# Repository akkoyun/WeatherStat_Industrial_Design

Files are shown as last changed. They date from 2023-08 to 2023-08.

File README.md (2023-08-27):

# P101DA<sup>V3</sup> Meteoroloji İstasyonu Tasarım Dokümantasyonu

| Modül Kodu | Açıklama | Durum |
|---|---|---|
| [P101DA-Base](P101DA-Base/Readme.md) | Meteoroloji istasyonu ana ünite | Tasarım bitme aşamasında ana yapı kesinleştirildi |
| [P101DA-Rain](P101DA-Rain/Readme.md) | Kovalı yağmur sensörü ünitesi | Tasarım bitme aşamasında ana yapı kesinleştirildi |
| [P101DA-Soil](P101DA-Soil/Readme.md) | Kademeli toprak sıcaklık sensörü ünitesi  | Tasarım bitme aşamasında ana yapı kesinleştirildi |
| [P101DA-UnderLeaf](P101DA-UnderLeaf/Readme.md) | Yaprak altı sıcaklık ve nem ölçüm ünitesi | V3 versiyonunda kullanılmayacak    |

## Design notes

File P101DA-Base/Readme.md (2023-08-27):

 # P101DA - Meteoroloji İstasyonu Base Ünite  &nbsp; &nbsp; 

| Parça Kodu | Parça Açıklaması | Parça Boyutları | Parça Malzemesi | Kullanım Adedi |
|---|---|---|---|---|
| [C111DA](C111DA/) | Üst Gövde | Ø245 x 100 mm | ABS | 1 |
| [C112BA](C112BA/) | Radyasyon Kalkanı Yaprakları | Ø230 - 46.4 mm  | ABS | 5 |
| [C113CA](C113CA/) | Üst Gövde Alt Kapağı | Ø244.4 - 140 mm | ABS | 1 |
| [C114CA](C114CA/) | Alt Gövde | Ø230 - 54,2 mm  | ABS | 1 |
| [C115BA](C115BA/) | Alt Kapak | Ø235 - 21 mm | ABS | 1 |
| [C116AA](C116AA/) | UV Sensör Merceği | 5x16x36mm | ABS | 1 |
| [PV Cell](PV%20Cell/) | Solar Panel | Ø180 x 2 mm | Monocrystal | 1 |
| [Diğer Parçalar](Diğer/) | | | | |

Bahsi geçen parçalar birleştirilerek P101DA-Base Ünitesi oluşturulmaktadır. </br>

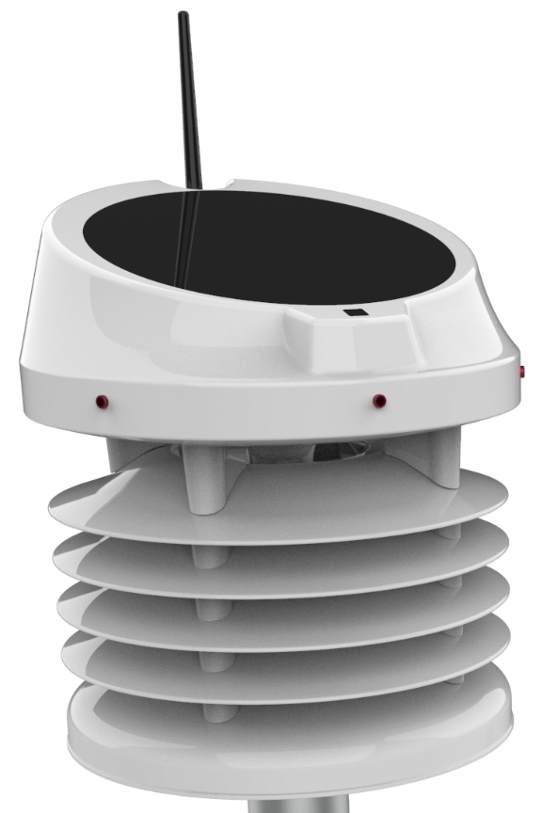
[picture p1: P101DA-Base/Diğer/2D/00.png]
Base ünitenin temsili resmi


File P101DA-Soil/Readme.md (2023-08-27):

# P101DA - Meteoroloji İstasyonu Soil Ünite &nbsp; &nbsp; 

| Parça Kodu | Parça Açıklaması | Parça Boyutları | Parça Malzemesi  | Kullanım Adedi |
|---|---|---|---|---|
| [M403AA](#m403aa) |Sıcaklık Sensörü Alt Metal Parça | |  Pirinç | 1 |
| [M404AA](#m404aa) |Sıcaklık Sensörü Orta Metal Parça  | |  Pirinç | 3 |
| [H903AA](#h903aa) |PVC Boru | |  PVC | 4 |
| [H904AA](#h904aa) |Üst Kapak | |  PVC | 1 |

Bahsi geçen parçalar birleştirilerek P101DA-Soil cihazı plastik aksamı oluşturmaktadır. 

## Eksikler ve Yapılacaklar
- 
</br>

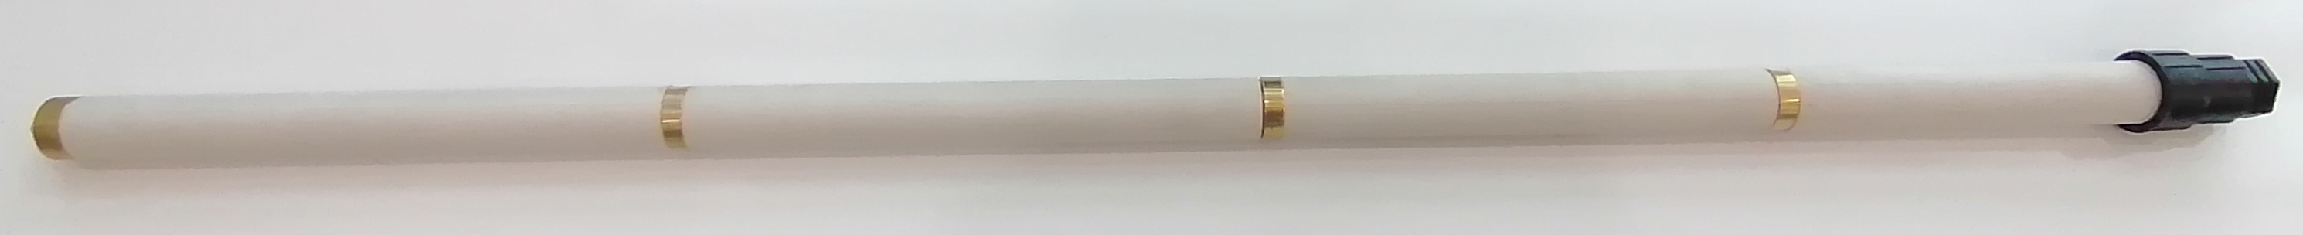
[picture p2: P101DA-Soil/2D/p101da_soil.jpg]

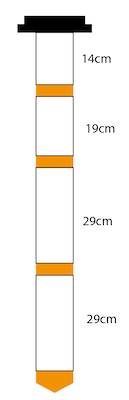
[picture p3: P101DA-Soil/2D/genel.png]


---
# M403AA Sıcaklık Sensörü Alt Metal Parça &nbsp; &nbsp; 
| Parça Kodu | Parça Açıklaması | Parça Boyutları | Parça Malzemesi  | Kullanım Adedi |
|---|---|---|---|---|
| M403AA |Sıcaklık Sensörü Alt Metal Parça | Ø32x38.5 mm |  Pirinç | 1 |

## Açıklama
Toprak altı ısı sensörünün 90cm derinlikteki ısıyı sensöre aktaracak parçadır.</br>
Özel olarak ürettirilmektedir.</br>
İç kısmında NTC sensör yerleştirilen Ø2x8 mm delik vardır.</br>

## Eksikler ve Yapılacaklar
    - 
</br>

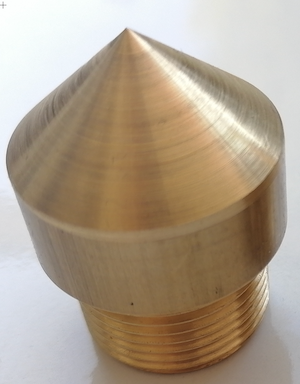
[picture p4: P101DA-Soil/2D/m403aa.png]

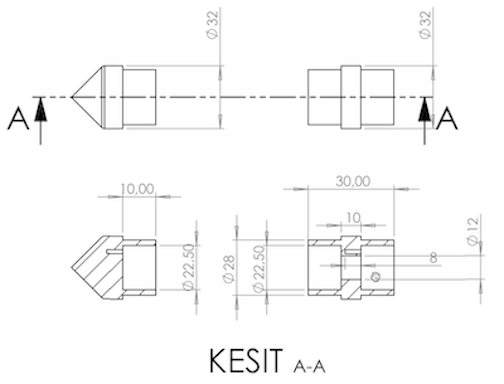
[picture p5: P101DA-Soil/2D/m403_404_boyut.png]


---

# M404AA Sıcaklık Sensörü Orta Metal Parça &nbsp; &nbsp; 
| Parça Kodu | Parça Açıklaması | Parça Boyutları | Parça Malzemesi  | Kullanım Adedi |
|---|---|---|---|---|
| M404AA |Sıcaklık Sensörü Orta Metal Parça | Ø32x30 mm |  Pirinç | 3 |

## Açıklama
Toprak altı ısı sensörünün 10/30/60cm derinlikteki ısıyı sensöre aktaracak parçalardır.</br>
Özel olarak ürettirilmektedir.</br>
İç kısmında NTC sensör yerleştirilen Ø2x8 mm delik vardır.</br>

## Eksikler ve Yapılacaklar
    - 
</br>

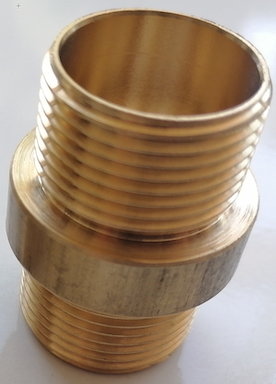
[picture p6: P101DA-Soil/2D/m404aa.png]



---

# H903AA PVC Boru &nbsp; &nbsp; 
| Parça Kodu | Parça Açıklaması | Parça Boyutları | Parça Malzemesi  | Kullanım Adedi |
|---|---|---|---|---|
| H903AA |PVC Boru | Ø32x5mm-29 cm |  PVC | 2 |
| |PVC Boru | Ø32x5mm-19 cm |  PVC | 1 |
| |PVC Boru | Ø32x5mm-14 cm |  PVC | 1 |

## Açıklama
Metal parçaları birleştirmek için kullanılan PVC borulardır.(Dış Çap: 32mm, Et Kalınlığı:5mm)</br>
29/19 cm olan parçalar içten yivlidir(3/4"). Erkek yivli metal parçalar bu yivlere bağlanır.</br>
14 cm olan parçanın bir tarafı dişi yivli (3/4") diğer tarafı erkek yivlidir(1").</br>
Erkek yivli tarafına üst kapak takılır.</br>

## Eksikler ve Yapılacaklar

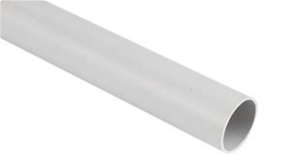
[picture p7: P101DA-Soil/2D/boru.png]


---

# H904AA Üst Kapak &nbsp; &nbsp; 
| Parça Kodu | Parça Açıklaması | Parça Boyutları | Parça Malzemesi  | Kullanım Adedi |
|---|---|---|---|---|
|H904AA |Üst Kapak | |  PVC | 1 |

## Açıklama
1" dişi yivli kör tapadır.</br>
14 cm PVCnin erkek yivli kısmına takılır.</br>
Üzerine G12-4p Mike socket takılacaktır.</br>

## Eksikler ve Yapılacaklar

## __
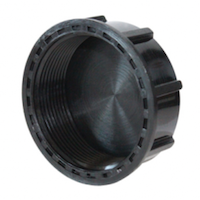
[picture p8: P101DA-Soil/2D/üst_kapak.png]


---

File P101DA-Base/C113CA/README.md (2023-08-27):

# C113CA - Üst Kapak Alt Parçası   &nbsp; &nbsp; 

| Parça Kodu | Parça Açıklaması | Parça Boyutları | Parça Malzemesi | Kullanım Adedi |
| --- | --- | --- | --- | --- |
| C113CA | Üst Kapak Alt Parçası | Ø244.4 - 140 mm | ABS | 1|

## Açıklama
C113CA parçası C111CA ve C112BA parçaları arasında bulunan parçadır.Bu kutunun ölçüleri Ø244 x 139.5 mm olup Ø3mm ölçüsünde olan 4 bağlantı deliğinden C111BA parçasına bağlanmaktadır.

Yan görünümünde bulunan 35,5x19,3mm olan ölçünün merkez deliği Ø1.5 olan delikten tasarlamış olduğumuz Sıcaklık-Nem sensörü bağlantısı yapılır.

Manuel veri gönderme butonu için geliştirdiğimiz PCB kartının üzerinde Ø210 ölçüsünde bulunan ve  Ø3,5 butonun geçeceği delik Ø1.7 olan 2 adet kart bağlantı deliği ile birlikte montajlanacaktır.

15x0.5mm ölçüde olan yarıktan sistemin aktif hale gelmesi için gerekli olan pil bağlantısının altında bulunan bantların dış tarafa çıkarılması için kullanılır.

13,3x6mm olan kanaldan C114BA parçasına bağlı olan mike soketin kablo bağlantısının soketinin geçebilmesi için tasarlanmıştır.

## Teknik Bilgi
Malzeme:ABS Erime Sıcaklığı:210 ~ 280℃ Ağırlık:300 gram Hacim:141 cm3 

## Revizyon \[BA-->CA][08.2022]

    -Pil koruma bandı çizgileri kapatıldı.
    -TH Sensör yeri revize edildi.
    -Üst ünite ile bağlantı şekli değiştirildi.
    -Th sensör kartı için çekmece yapıldı.
</br>

## C113CA <sub> R1<sub> (04.10.2022)
    - Sensör için aşağı inen çıkıntının boyu kısaltıldı.
  
## C113CA <sub> R2<sub> (14.10.2022)
    - Sensör için aşağı inen çıkıntının boyu 26mm uzatıldı.
    - Kart çekmecesi aralığı PCB kalınlığına uygun şekilde 1.6mm yapıldı.

## Maliyet Bilgisi
Bu alana parçanın seri üretim maliyet tabloları yer alacaktır.

    Yapılacak değişiklikler,
    - Yapılan değişikliklere göre mevcut kalıp revizyonu yaptırılacak.

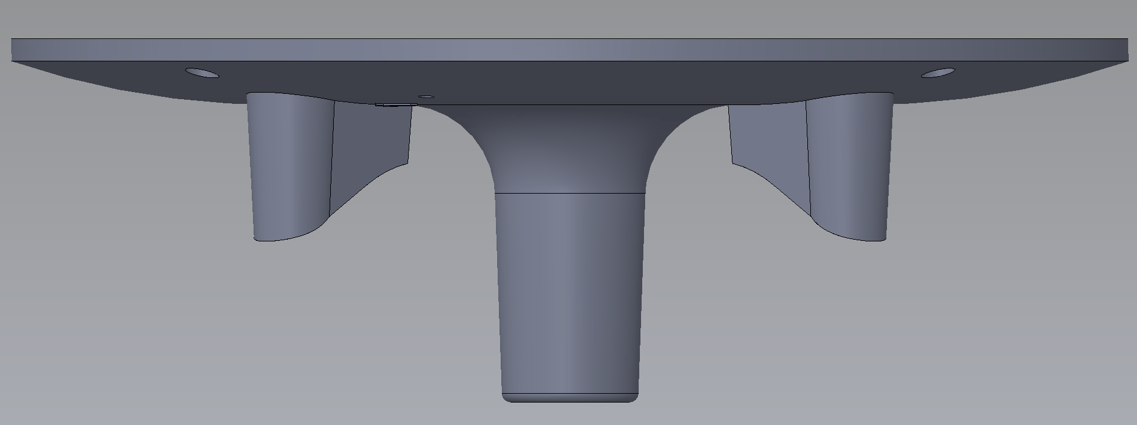
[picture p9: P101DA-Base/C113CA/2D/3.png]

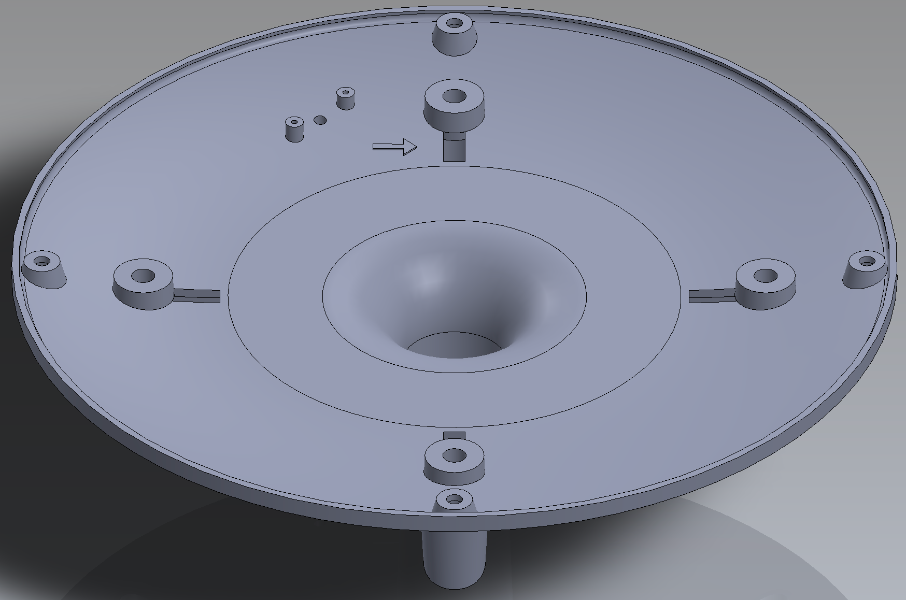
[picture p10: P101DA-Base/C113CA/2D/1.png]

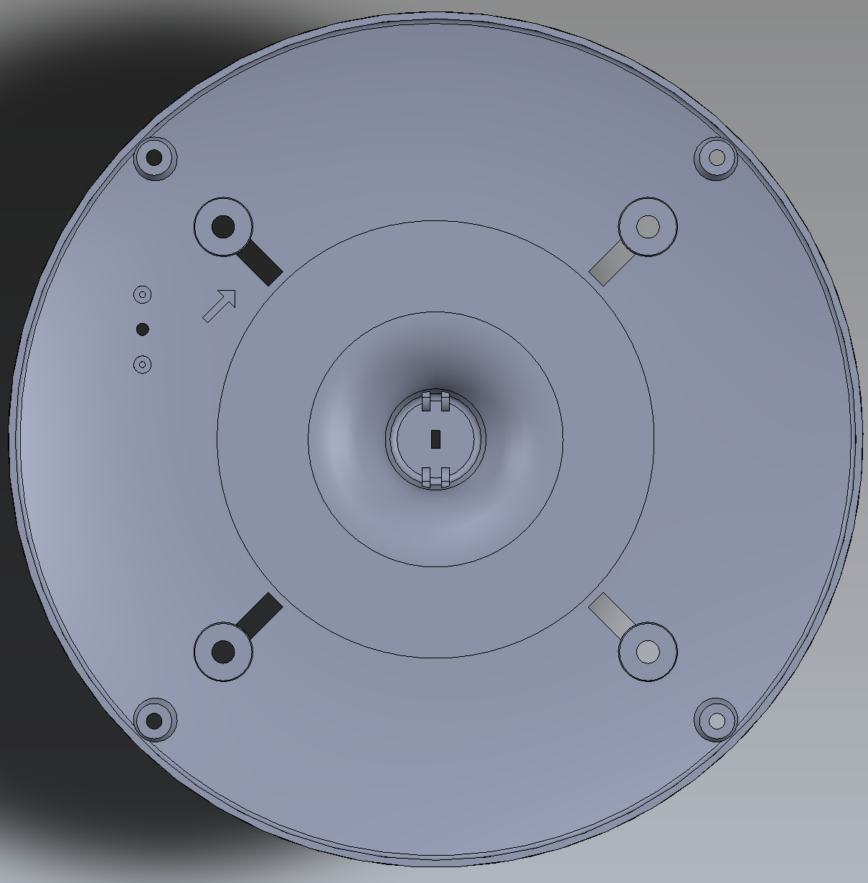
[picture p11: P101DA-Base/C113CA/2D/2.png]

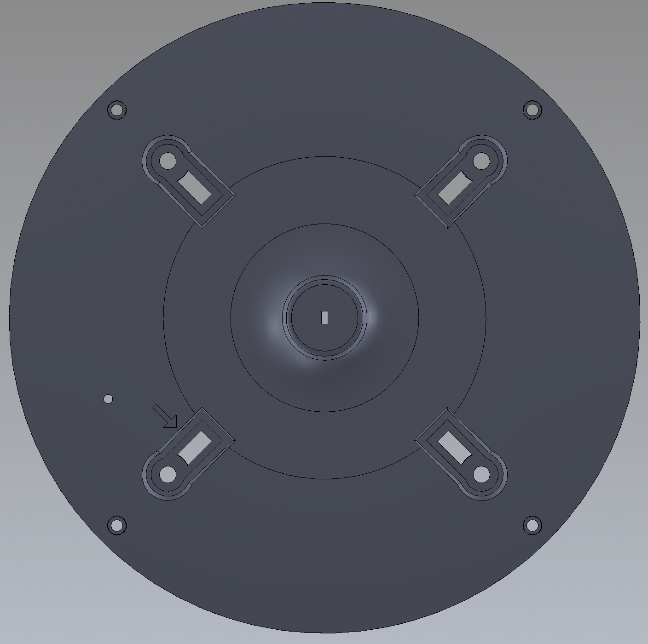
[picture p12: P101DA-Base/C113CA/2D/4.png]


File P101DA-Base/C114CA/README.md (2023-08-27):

# C114CA - Alt Zemin   &nbsp; &nbsp; 

 Parça Kodu | Parça Açıklaması | Parça Boyutları | Parça Malzemesi | Kullanım Adedi |
| ---------- | ---------------- | --------------- | --------------- | -------------- |
| C114CA     | Alt Zemin       | Ø230 x 54.2 mm | ABS             | 1|

## Açıklama
C114CA parçası P101DA ürünün en altında bulunan kapaktır.Bu kapağın ölçüleri Ø230-54,2mm olup Ø171,8mm olan kısımlarından üst parçalarına bağlantı sağlanmaktadır.6,7-16,8mm kanalından alt kısımdan gelen bağlantı soketinin geçeceği kanaldır.

## Teknik Bilgi
Malzeme:ABS Erime Sıcaklığı:210 ~ 280℃ Ağırlık:250 gram Hacim:238 cm3 

## Revizyon \[BA-->CA][08.2022]

    -Kablo geçişler için açık olmayan iki kanal yeri de açıldı.
</br>

## Maliyet Bilgisi
Bu alana parçanın seri üretim maliyet tabloları yer alacaktır.

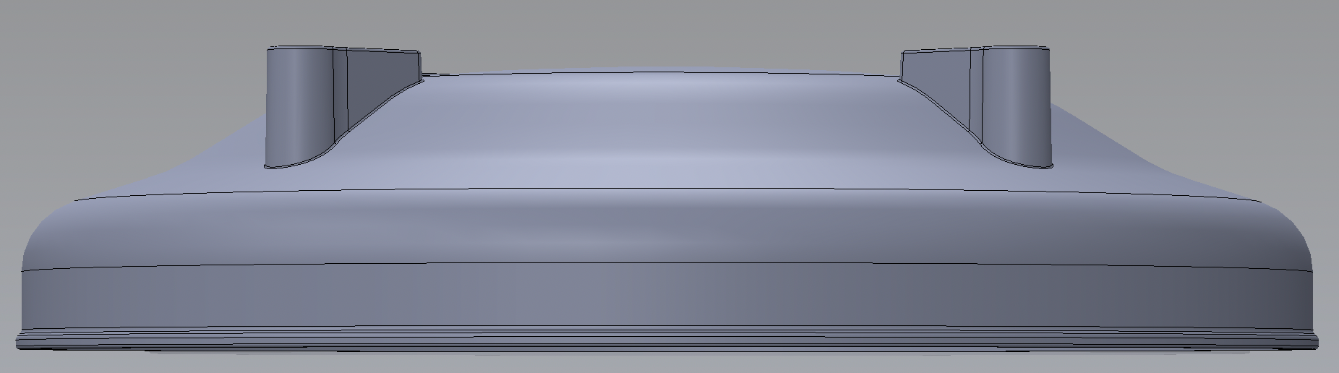
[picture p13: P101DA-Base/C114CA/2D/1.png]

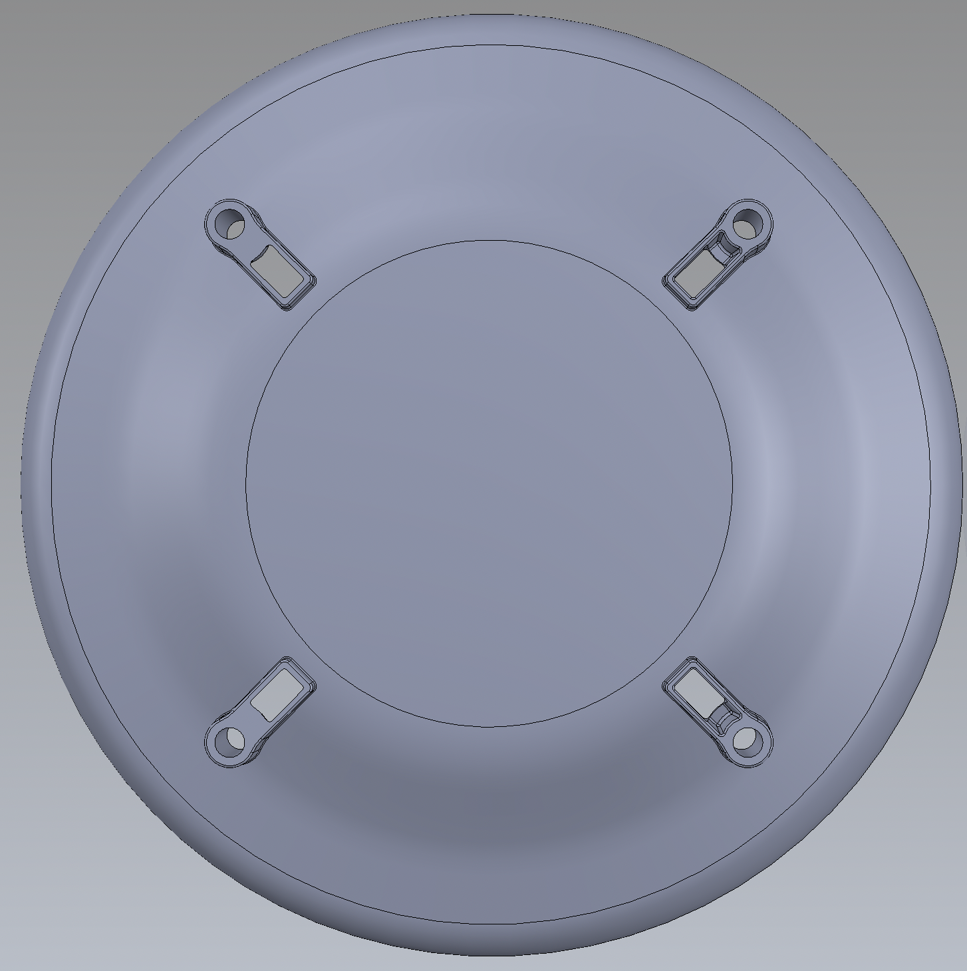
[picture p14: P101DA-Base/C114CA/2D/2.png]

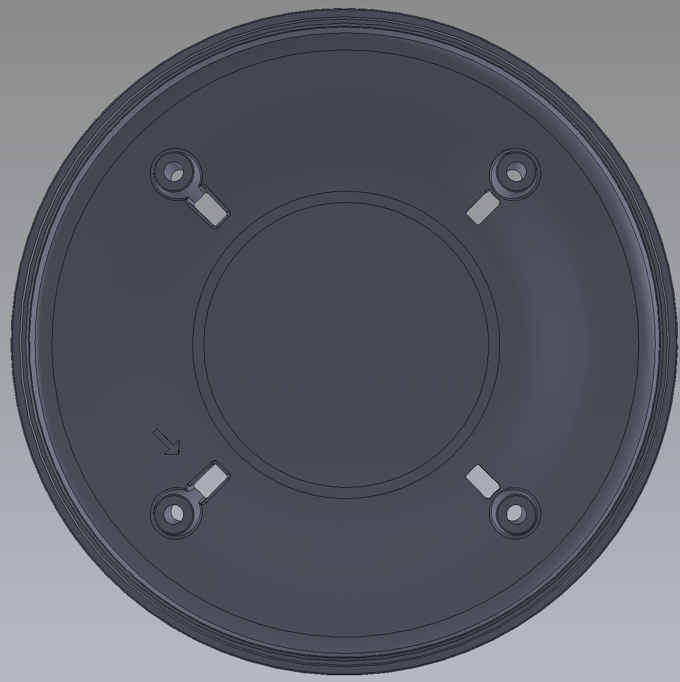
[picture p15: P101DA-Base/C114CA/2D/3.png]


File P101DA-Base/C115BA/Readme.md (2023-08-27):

# C115BA - Alt Kapak   &nbsp; &nbsp; 
| Parça Kodu | Parça Açıklaması | Parça Boyutları | Parça Malzemesi | Kullanım Adedi |
| --- | --- | --- | --- | --- |
| C115BA | Alt kapak | Ø235 x 21 mm | ABS | 1 |
## Açıklama
C115BA parçası P101DA ürününün en altında bulunan kapaktır.Bu kapağın ölçüleri Ø235-21mm olup kapağın merkezinden bağlantı ayağı için 40-30mm'lik dikdörtgen bir delik vardır.

Merkezine doğru mike soketin bağlanması için 12,2-11,1mm'lik bir delik mevcuttur.

Ø171,8mm merkez ölçüsü ve Ø6,5mm'lik 4 adet saplama bağlantı delikleri mevcuttur.

## Teknik Bilgi
Malzeme:ABS Erime Sıcaklığı:210 ~ 280℃ Ağırlık:140 gram Hacim:140,6 cm3 

## Revizyon \[AA-->BA][08.2022]

    - İzi olan soket yeri açıldı.
    - Diğer iki soket yerine ihtiyaç olduğunda kırılabilecek şekilde iz bırakıldı.
</br>

## Maliyet Bilgisi
Bu alana parçanın seri üretim maliyet tabloları yer alacaktır.


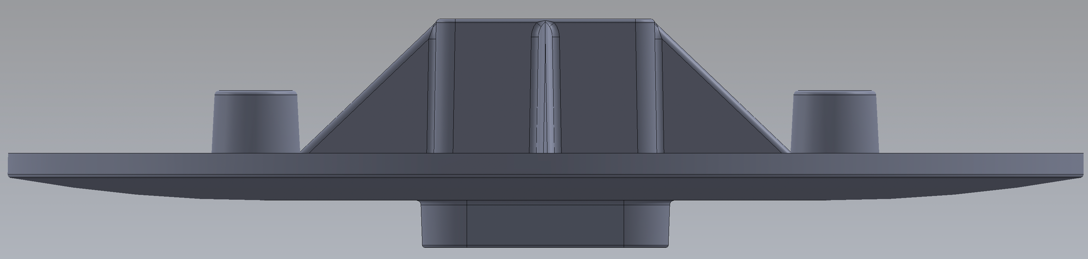
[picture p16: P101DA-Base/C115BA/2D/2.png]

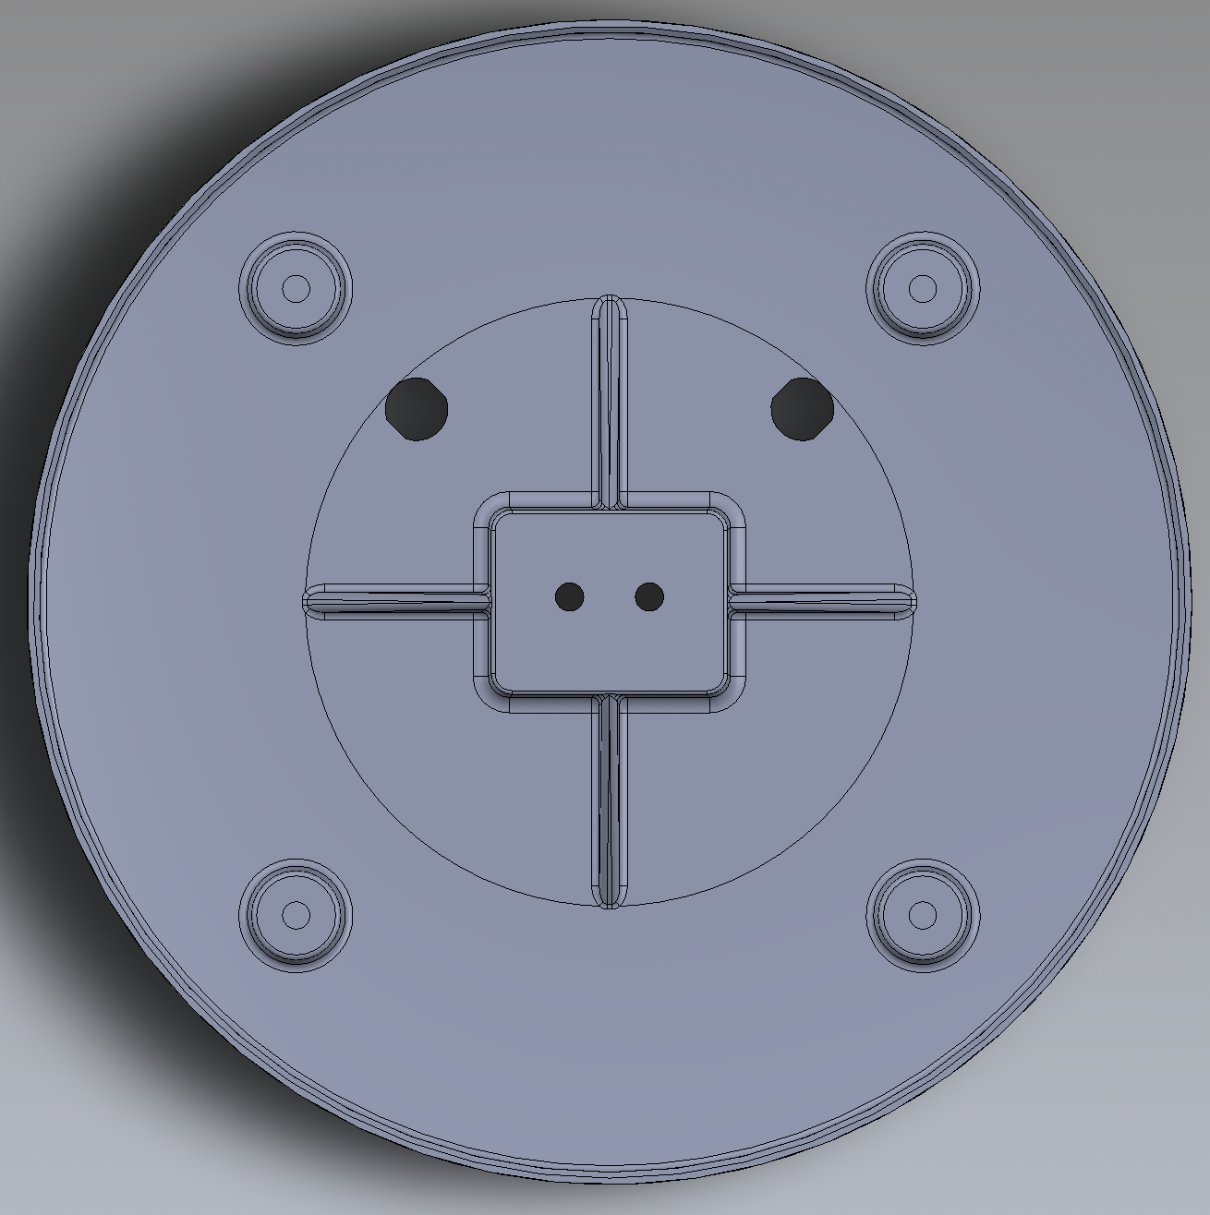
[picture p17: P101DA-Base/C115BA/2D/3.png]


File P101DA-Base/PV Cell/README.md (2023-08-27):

# Solar Panel  &nbsp; &nbsp; 

| Parça Kodu | Parça Açıklaması | Parça Boyutları | Parça Malzemesi | Kullanım Adedi |
| --- | --- | --- | --- | --- |
| SP | Solar Panel | Ø180 x 2 mm | Monocrystal | 1|

## Açıklama
Solar panel monocrystal 5V ?W

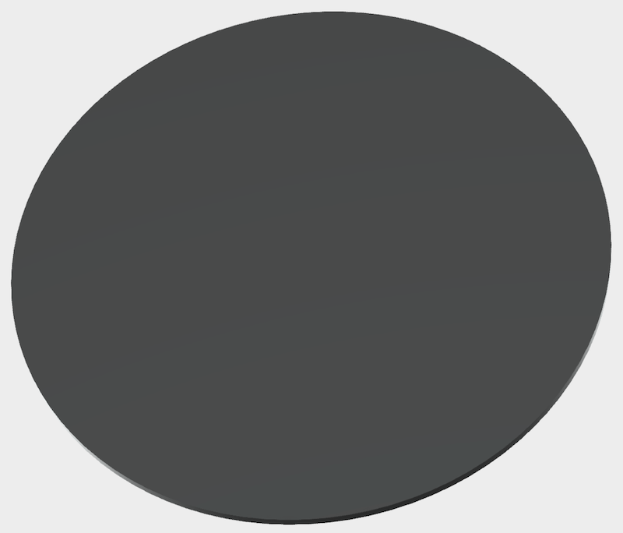
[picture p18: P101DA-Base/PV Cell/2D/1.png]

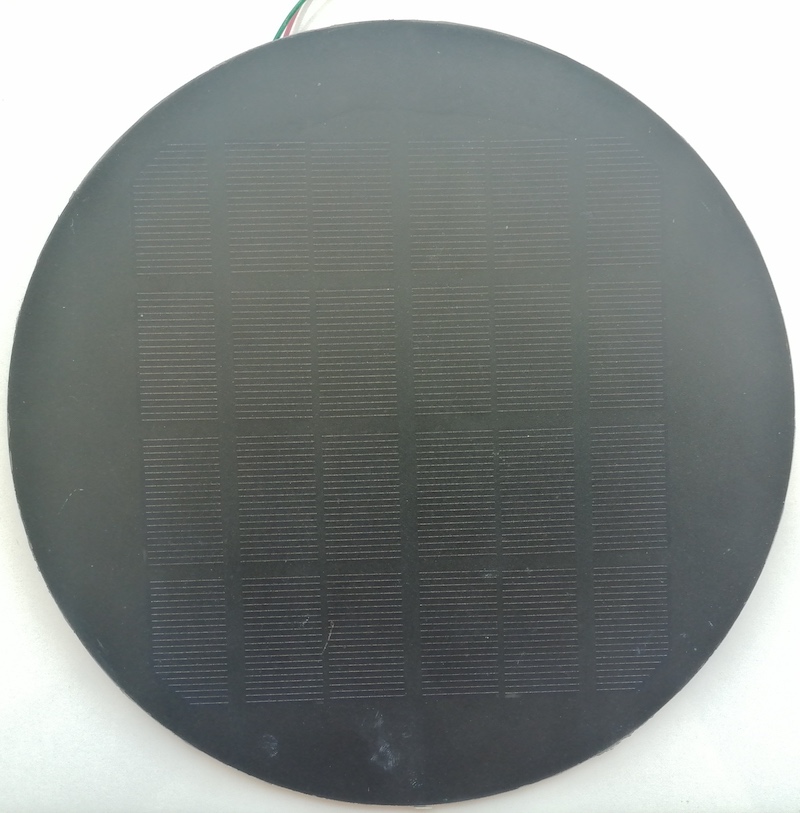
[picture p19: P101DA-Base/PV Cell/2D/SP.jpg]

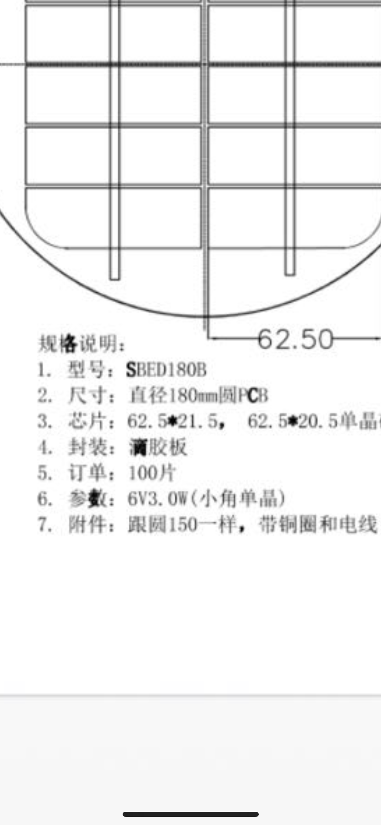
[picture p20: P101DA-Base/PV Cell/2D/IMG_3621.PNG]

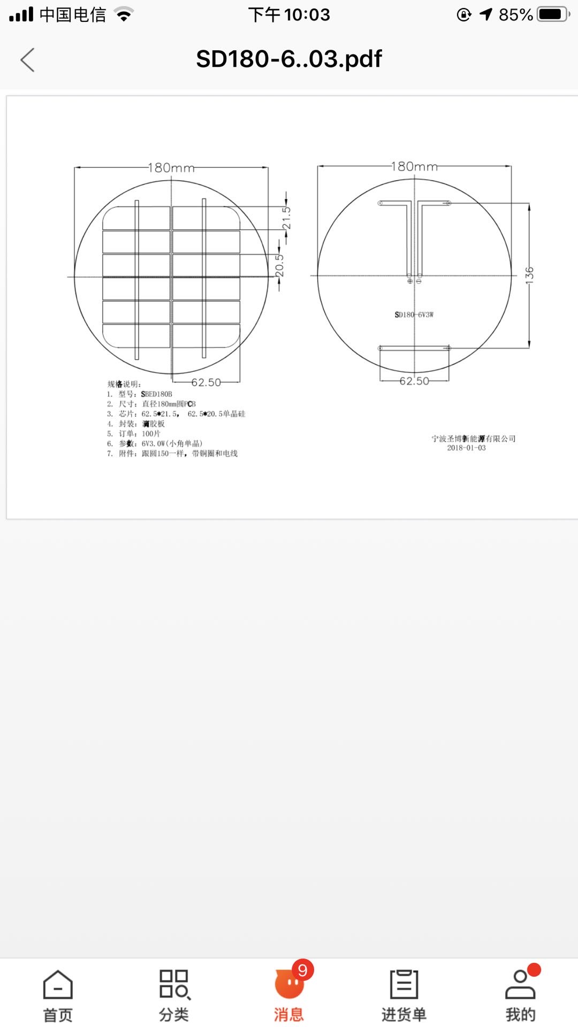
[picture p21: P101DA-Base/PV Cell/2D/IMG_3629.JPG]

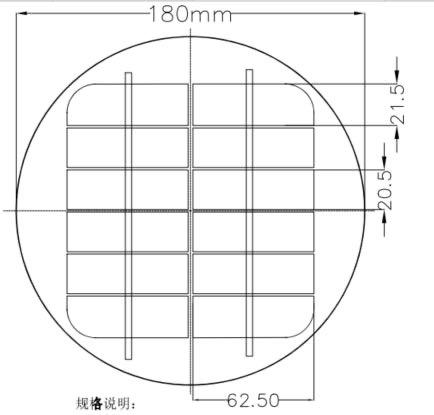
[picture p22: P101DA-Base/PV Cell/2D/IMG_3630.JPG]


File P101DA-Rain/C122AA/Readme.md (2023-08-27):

# C122AA YAĞMUR ÖLÇÜM ALT GÖVDE  &nbsp; &nbsp; 
| Parça Kodu | Parça Açıklaması | Parça Boyutları | Parça Malzemesi | Kullanım Adedi |
| --- | --- | --- | --- | --- |
| C121AA | Alt gövde | Ø213.6 x 42.8 | ABS | 1 |

## Açıklama
Yağmur ölçüm ünitesinin alt kısmıdır. Bu ürün 6 xxx vida ile [C121AA](../C121AA/Readme.md) parçasına bağlanır.</br>
[Kepçe](../C123AA/Readme.md) 5mm [Kepçe Pimi]() ve iki sekman ? ile bu üniteye bağlanır.</br>
[Zemin Düzenleyici Terazi]() bu ünite üzerine yapıştırılır.</br>
Elektronik kart bu ünitedeki kızağa sürülerek takılır ve bulunduğu bölüm epoksi ile doldurulur.</br>
Kepçe hacmi [Kepçe kalibrasyon Vidası](../H111AA/Readme.md) ile ayarlanır.</br>
[Metal Kaide M301AA](../M301AA/Readme.md) 4adet X vida ile bu üniteye bağlanır.</br>

# Maliyet

# Eksikler ve Yapılacaklar
    - Kalibrasyon vidası ve alt kaide bağlantıları için insert/kalıp somun kullanılıyor mu?
    - Kullanılan insert somunların ölçüleri?

# 2D Resimler

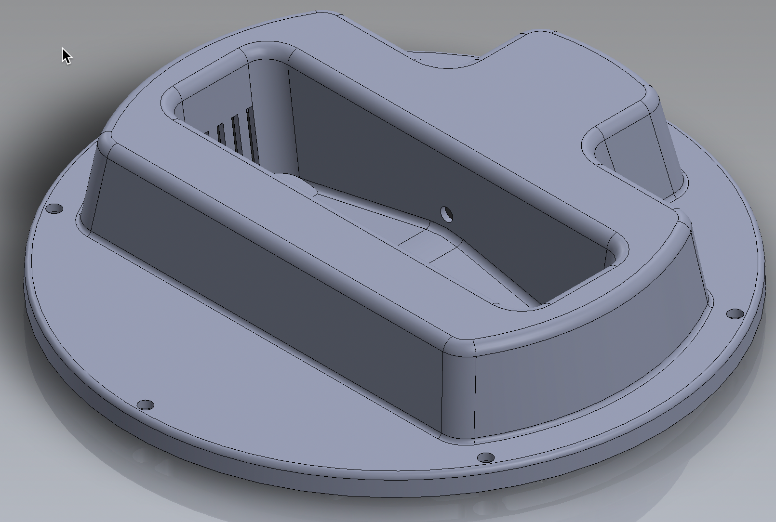
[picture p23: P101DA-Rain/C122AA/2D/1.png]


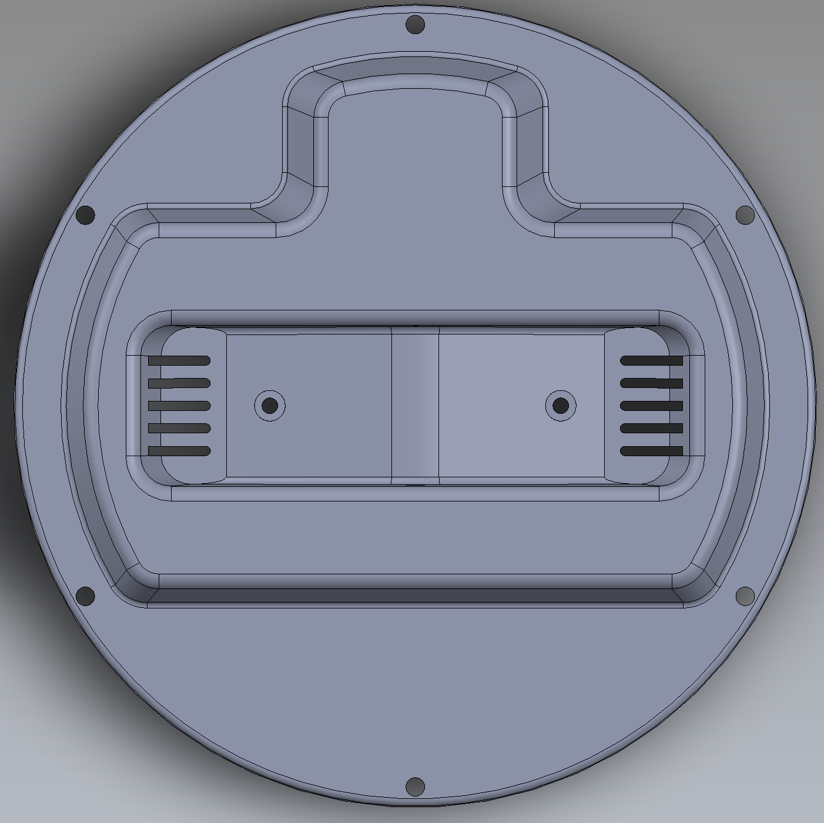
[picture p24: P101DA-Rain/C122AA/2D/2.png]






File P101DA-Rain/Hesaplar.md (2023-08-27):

# Yağmur Modülü Hesaplamaları

**Yağış miktarı:** Yağmur miktarı, toprak yüzeyine düşen suyun, buharlaşmaya ve toprağa 
sızmaya uğramadan, meydana getireceği yükseklik ile tayin olunur. Yağmurun yüksekliği 
milimetre ile ifade edilir, Suyun özgül ağırlığı 1 gr/cm<sup>3</sup> olduğuna 
göre 1 m<sup>2</sup> alanda 1 mm yüksekliğindeki suyun ağırlığı 1 kg eder. 1 m<sup>2</sup> 
yüzey üzerinde 1 mm yüksekliğindeki yağış, 1 cm<sup>2</sup> ye düşen 1 kg yağışa eşittir. 

Yani; 1 mm yağış = 1 kg/m<sup>2</sup> = 1 litredir.

# Su Haznesi Hacmi

| Süre(dk)  | Miktar(mm) | Yer  |  Tarih |
|:--:|---:|:---|---:|
| 5dk| 50.5| HOPA| 7.07.1988|
|10dk| 60.6| HOPA| 7.07.1988|
|15dk| 70.7| HOPA| 7.07.1988|
|30dk| 90.9| HOPA| 7.07.1988|
| 1SA|133.8|BARTIN,ULUS,CEYÜPLER| 10.08.2021|
| 2SA|210.0|BARTIN,ULUS,CEYÜPLER|10-11.08.2021|
| 3SA|252.8|BARTIN,ULUS,CEYÜPLER|10-11.08.2021|
| 4SA|332.3| ANTALYA| 4.11.1995|
| 5SA|374.3| ANTALYA| 4.11.1995|
| 6SA|390.3| ANTALYA| 4.11.1995|
| 8SA|410.4| ANTALYA| 4.11.1995|
|12SA|428.1| ANTALYA| 4.11.1995|
|18SA|464.8| MARMARİS|10-11.12.1992|
|24SA|490.8| ANTALYA-KEMER|16-17.12.2018|

Meteoroloji GM Resmî sitesinde verilen maksimum yağış miktarları incelendiğinde haznemizin 
hacmi 1. Satırdaki 5dk-50,5 mm yağış değerlerini karşılamalıdır. 

Yağış alan yüzey alanımız 16cm çap için $(\pi r^2)$ 0,02 m<sup>2</sup> dir. 
1m<sup>2</sup> 50,5 mm yağış alırsa, 0,02 m<sup>2</sup> 1,01 mm yağış alır.

1 m <sup>2</sup>   &nbsp;&nbsp;&nbsp;&nbsp;&nbsp;&nbsp;50.5 mm

0.02 m <sup>2</sup>   &nbsp;&nbsp;&nbsp;&nbsp;x = 1,01 mm

Bu hesaplamaya göre haznemizin minimum **hacmi** 1,01 lt veya 1010 cm<sup>3</sup> olmalıdır.

# Su Boşalma Süresi

Ölçümlerimizin saatlik periyotlarla yapılacağı düşünüldüğünde belirlenen haznemizin içinde
 bulunan suyun maksimum 1 saat içinde boşalması gerekmektedir. Bunun için kabımızın şekli 
 konik olarak düşünüldüğünde koniğin suyu boşaltma ucunun çapı çok iyi belirlenmelidir. 
 Bunun için 
 [diego.assencio.com](https://diego.assencio.com/?index=62f54ab6114d473b6933ad5bf5a5fc88) 
 sitesindeki hesaplamalardan yararlanılmıştır. Şeklimiz 
 ve oranlar aşağıdaki verilen şekle yakındır.



a = 1,5 = 0,15 cm  mm &nbsp;&nbsp; b = 8cm &nbsp;&nbsp; h1 = 41mm = 4.1cm &nbsp;&nbsp; 
h2 = 27mm = 2.7cm &nbsp;&nbsp; $\pi$ = 3,14

**Silindir Hacmi:** $\pi r^2h$ = 823,936 ∼ 824 cm<sup>3</sup>
 
**Koni Hacmi:** $\pi(R^2+r^2+Rr)/3$ = 184,326 ∼ 184 cm<sup>3</sup>

**Toplam Hacim:** $824+184$ = 1008 cm<sup>3</sup> 

1008 cm<sup>3</sup>  = 1.008 Litre ∼ 1.01 Litre

 

 (g = 98 cm/s<sup>2</sup> )

Bu formül huninin üst çap, alt çap ve yüksekliğinin bilindiği değerler için huninin 
tam boşaltma zamanının hesaplanması için kullanılmaktadır. Kullandığımız şekil 
bu formüle uygulandığı takdirde hesabın gerçek değerlere yakın olacağı düşünülmektedir. 
Formüle yukarda bilinen değerler ve boşaltma çapı için 3mm girildiğinde;

= 211 saniye = **3 dakika 31 saniye**

[**Yapılan Testte Sonuç:** 3  dakika 7 saniye]

(Hesaplanan ile ölçülen arasında 24 saniyelik bir fark var.)

# Kepçe Hacmi

Yukarıda MGM’nün tablosunda verilen 1 saatlik maksimum değer 133 mm olduğuna göre,

kepçe hacmimizi en az 4 ml, en fazla 10 ml olabilir.
Kepçe sayacımızı **1023 puls/saat** olarak alırsak;

Sensörümüz en az 4×1023 = 4,092 litre/saat,
(en fazla 10×1023 = 10,230 litre/saat) ölçüm yapabilir.

Kullanmayı planladığımız 6 ml, $6×1023=6,138$ litre/saat

Çapımız 16cm olarak belirlendiğinde m<sup>2</sup>’ye oran katsayısı $(1/0,02)$'den $50$’dir.

Sensörümüzün saatte en az ölçtüğü 6,138 litre yağmur değeri m<sup>2</sup>'de $6,138×50=306,9$ litredir.

Sonuç olarak **seçtiğimiz değerler maksimum yağış miktarını ölçmeye yeterlidir.**

# Hassasiyet

Hassasiyet = Kepçe Hacmi × 1m<sup>2</sup>'ye oranı

6 ml × 50 =300 ml     (1Lt➔1000mLt➔1mm olduğundan)

**Hassasiyet** = 0,3 mm ‘dir.

# Karşılaştırma Tablosu

|Teknik Özellikleri|[Lambrecht LMP02](https://metos.at/portfolio/lambrecht-rain-gauge/)|[Pessl IM523](https://www.agriexpo.online/prod/pessl-instruments-gmbh/product-169962-14626.html)|[WS-601(Aliexpress)](https://turkish.alibaba.com/product-detail/rainfall-collected-tipping-bucket-rain-gauge-rain-sensor-60654605407.html)|WeatherStat(10 ml)|WeatherStat (10 ml)|birim|
|---|:---:|:---:|:---:|:---:|:---:|:---:|
|Huni Toplama Yüzey çapı | 16  |  16 | 20  | 16  | 16  | cm |
|Kepçe hacmi |  4  |  4  | 16  | 10  | 6  | cm<sup>3|
|Kepçenin dk maksimum devrilmesi |  80 | 60  | 60  | 35  | 68  | boşaltma|
|Darbe sayıcı max değer |4800 |3600 |3600 |2100 |3600 | pulse/h |
|Ölçüm aralığı 0-max |  16 |  12 | 30  |17,5 |20,3 | mm/min  |
|Çözünürlük | 0,2 | 0,2 | 0,5 | 0,5 | 0,3 | mm |
|Doğruluk |  4  |  4  | 10  | 10  |  6  | ±% |
|Huni toplama | 201 | 201 | 314 | 201 | 201 | cm<sup>2|
|Boyutlar / Ağırlık | - | - |  -  | - | - | |

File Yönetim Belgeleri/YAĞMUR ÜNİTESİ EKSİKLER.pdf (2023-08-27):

# YAĞMUR ÜNİTESİ EKSİKLER


C121AA YAĞMUR ÖLÇÜM HUNİ GÖVDE Eksikler Bu parçanın STL ve Step dosyaları eksik. Alt ünite ile bağlantıda kullanılacak 6 vida için kalıba insert somun yerleştirilecek mi?


C122AA YAĞMUR ÖLÇÜM ALT GÖVDE Eksikler ve Yapılacaklar Bu parçanın STL ve Step dosyaları eksik. Kalıba yerleştirilecek kalibrasyon vidası yeri için açık somun(insert) özellikleri Kalıba yerleştirilecek tabla vidalarının somun (insert) özellikleri


C123AA YAĞMUR ÖLÇÜM KEPÇE Bu parçanın STL ve STEP dosyaları eksiktir.

C124AA Taç Kuşkonmaz Pimi 12 adet Eksikler ve Yapılacaklar Hangi malzemeden yapılacağı ve boyutları belirlenecek. Teknik çizimleri eklenecek


C125AA Orta Kuşkonmaz Yuvası STL ve STEP dosyası eksik.

C126AA Orta Kuşkonmaz Pimi 1adet Hangi malzemeden yapılacağı ve boyutları belirlenecek. Teknik çizimleri eklenecek

H111AA Kepçe Kalibrasyon Vidası Alt Ünite C122AA'ya bağlayan 2 vidadır. Boyutları ve teknik resmi eksik.

H112AA Metal Kaide Montaj Vidası (Metal Kaide M301AA'yı Alt Ünite C122AA'ya bağlayan 4 vidadır.) Vida özellikleri ve boyutları eksik


H122AA Seviye Ayar Saplaması (M301AA Metal Kaide’ye kaynatılacak 3 saplama) Özellikleri ve boyutları belirlenecek

H801AA Seviye Ayar Yayı (Kaynatılan saplamalara geçecek) Özellikleri ve boyutları belirlenecek

H301AA Seviye Ayar Somunu Saplamalara montaj kolunun altından sıkılacak 2x3 adet Özellikleri ve boyutları belirlenecek

H401AA Seviye Ayar Yaylı Rondela Somunlarda montaj kolu arasında 1er adet Özellikleri ve boyutları belirlenecek

H701AA Kepçe Pimi Eksik yok


H602AA Kepçe Pimi Segmanı Eksik yok

H901AA Kepçe Mıknatısı Eksik yok

H910AA Baloncuklu Yuvarlak Su Terazisi Eksik yok


M101AA YAĞMUR ÜNİTESİ MONTAJ KOLU Eksikler: sldprt dosyası eksik


M301AA Metal Kaide Eksikler sldprt dosyası yok. Konnektör bağlantı yeri yok.


M302 Montaj Kolu Kelepçesi Sldprt dosyası eksik.


H210 Montaj Kolu U-Cıvata Seti Eksikler Boyutları ve malzeme bilgisi

M113AA Alt Gövde-Huni Bağlantı vidaları 6 adet Eksikler Özellikleri ve boyutları ?

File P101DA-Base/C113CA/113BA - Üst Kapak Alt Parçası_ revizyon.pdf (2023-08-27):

## A Side

## B Side


Buradan itibaren kesilecek
aşağıdakine yakın ovallikte sonlandırılacak

## A Side

## B Side

Sonlandırılan yerde
2x5mm bir açıklık olacak

Bu tarafta da
kartı sokup süreceğimiz
yağmur sensöründeki gibi
kart kızağı olacak
PCB kalınlığı 1,6 mm

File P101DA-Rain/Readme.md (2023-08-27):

# P101DA - Meteoroloji İstasyonu Yağmur Ünitesi &nbsp; &nbsp; 

| Parça Kodu | Parça Açıklaması | Parça Boyutları | Parça Malzemesi  | Kullanım Adedi |
|---|---|---|---|---|
| [C121AA](C121AA/) | Huni Gövdesi | | ABS | 1 |
| [C122AA](C122AA/) | Alt Gövde | | ABS | 1 |
| [C123AA](C123AA/) | Kepçe | | ABS | 1 |
| [C124AA](C124AA/) | Taç Kuşkonmaz Pimi | | ? | 12 |
| [C125AA](C125AA/) | Orta Kuşkonmaz Yuvası | | ABS | 1 |
| [C126AA](C126AA/) | Orta Kuşkonmaz Pimi | | ? | 1 |
| [M101AA](M101AA/) | Montaj Kolu | | Galvanizli Saç ? | 1 |
| [M301AA](M301AA/) | Metal Kaide | | Pas | 1 |
| [M302AA](M302AA/) | Direk Bağlantı Aparatı | | ? | 1 |
| [M401AA](M401AA/) | Kepçe Pimi | | Paslanmaz ? | 1 |
| [Diğer Parçalar](Diğer/) | 

Bahsi geçen parçalar birleştirilerek P101DA-Rain cihazını oluşturmaktadır.

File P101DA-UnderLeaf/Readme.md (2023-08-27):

# P101DA - Meteoroloji İstasyonu UnderLeaf Ünite &nbsp; &nbsp; 

| Parça Kodu | Parça Açıklaması | Parça Boyutları | Parça Malzemesi  | Kullanım Adedi |
|---|---|---|---|---|
| | | | | |

Bahsi geçen parçalar birleştirilerek P101DA-UnderLeaf cihazını oluşturmaktadır. 

***

    Yapılacaklar
    - Tasarım tamamlanacak.

***

    Belgelendirme Yapısı
    * Her bir parçaya ait detay teknik çizim PDF leri (2D klasöründe olacak).
    * Her bir parçaya ait katı modeller (3D klasöründe olacak).
    * Her bir parçaya ait tasarım dosyaları (SolidWorks klasöründe olacak).
    * Her bir parçaya ait malzeme detayları (Parça klasörü readme dosyasında olacak).
    * her bir parçaya ait ağrılık, hacim vb teknik bilgiler (Parça klasörü readme dosyasında olacak).
    * her bir parçaya ait imalat detayları ve maliyet bilgileri (Parça klasörü readme dosyasında olacak).

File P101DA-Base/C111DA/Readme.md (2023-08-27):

# C111DA - Üst Gövde &nbsp; &nbsp; 

| Parça Kodu | Parça Açıklaması | Parça Boyutları | Parça Malzemesi | Kullanım Adedi |
| --- | --- | --- | --- | --- |
| C111DA | Üst Gövde | Ø245 x 100 | ABS | 1 |

## Açıklama
C111DA parçası P101DA ürününün en üst kısmıdır. Bu ürün üzerinde

    -Main PCB (MCU, Pil, Dp Sensörler, diğer çevresel ICs)
    -UV Sensör Kartı
    -UV Sensör Merceği
    -Update Buton Kartı
    -Güneş Paneli
    -GSM ve GPS Anten
    -Rüzgar giriş bağlantı parçaları
parçarları yer almaktadır. 

## Teknik Bilgi
Malzeme:ABS Erime Sıcaklığı:210 ~ 280℃ Ağırlık:? gram Hacim:? cm3

## Maliyet Bilgisi
Bu alana parçanın seri üretim maliyet tabloları yer alacaktır.

## Revizyon \[CA-->DA](26.08.2022)

    -Güneş paneli eğimli hale getirildi.
    -Harici anten yeri iptal edildi. (İç kısımda Stick anten kullanılacak)
    -GPS anteni için iç kısımda 26x26mm yuva yapıldı.
    -Rüzgar ölçüm holleri eklendi. (6 adet)
    -PCB bağlantı yerleri değiştirildi.
    -Alt ünite ile bağlantı yerleri değiştirildi.
</br>

## C111DA  <sub>R1</sub> (04.10.2022)
    - PCB kartı vidalama delik yerleri değiştirildi.

</br>

## C111DA  <sub>R2</sub> (14.10.2022)
    - C111DA_R1 ile C113CA ile montaj uyumsuzluğu tespit edildi. Revize edildi.

</br>

## Yapılacaklar
    - C111DA_R1 ile C113CA birleşme noktası biraz geniş. Sert geçecek şekilde ayarlanacak.

</br>

## __








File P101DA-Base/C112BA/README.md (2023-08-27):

# C112BA - Radyasyon Kalkanı Yaprakları   &nbsp; &nbsp; 

| Parça Kodu | Parça Açıklaması | Parça Boyutları | Parça Malzemesi | Kullanım Adedi |
| --- | --- | --- | --- | --- |
| C112BA | Radyasyon Kalkanı Yaprakları | Ø230 x 46.4 | ABS | 5|

## Açıklama
C112BA parçası P101DA ürünün orta kısmında bulunan ve ürün üzerine 5 adet takılan parçadır.Bu parçanın ölçüleri Ø230-46.4 mm olup Ø172 olan yerinden diğer parçalara bağlanması için iç içe geçmeli bir yapısı vardır.

6.5x13.5 olan alanın birinden toprak sıcaklık sensörünün diğerinden ise Yağmur ölçüm ünitesinin kablosu geçmektedir.

## Teknik Bilgi
Malzeme:ABS Erime Sıcaklığı:210 ~ 280℃ Ağırlık:135 gram Hacim:100 cm3 

## Revizyon

    --
</br>

## Maliyet Bilgisi
Bu alana parçanın seri üretim maliyet tabloları yer alacaktır.










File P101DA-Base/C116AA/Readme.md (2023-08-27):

# C116AA UV Sensör Merceği &nbsp; &nbsp; 

| Parça Kodu | Parça Açıklaması | Parça Boyutları | Parça Malzemesi | Kullanım Adedi |
| --- | --- | --- | --- | --- |
| C116AA | UV Sensör Merceği| 5x16x36mm | ABS | 1 |

## Açıklama
UV Sensör Kartı ile birlikte  [C111DA - Üst Gövde](../C111DA/Readme.md) üzerine montaj edilir.</br>

## Eksikler ve Yapılacaklar
Teknik resim ve sldprt dosyaları eksik.</br>

## __




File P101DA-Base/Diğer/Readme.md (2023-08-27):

# Diğer Parçalar   &nbsp; &nbsp; 

| Parça Kodu | Parça Açıklaması |Parça Boyutları | Parça Malzemesi | Kullanım Adedi |
|---|---|---|---|---|
| [M201AA](#m201aa) | Direk | |  Paslanmaz | 1 |
| [H302AA](#h302aa) | Alt Kapak Kalıp İçi Somun | M6x14 mm |  Pirinç | 4 |
| [H123AA](#h123aa) | Base Toplama Saplaması | Ø6 - 195 mm |  Paslanmaz | 4 |
| [H303AA](#h303aa) | Saplama Sonlandırma Somunu | M6 Flanşlı |  Paslanmaz | 4 |
| [M102AA](#m102aa) | Direk Base Bağlantı Parçası | |  Paslanmaz | 1 |
| [H125AA](#h125aa) | Direk Base Bağlantı Saplaması | Ø6 - 20 mm |  Paslanmaz | 2 |
| [H304AA](#h304aa) | Direk Base Bağlantı Somunu | M6 |  Paslanmaz | 2 |
| [H124AA](#h124aa) | Direk Base Bağlantı Civatası | M5x12 mm |  Paslanmaz | 2 |
| [H305AA](#h305aa) | Direk Base Bağlantı Somunu | M5 |  Paslanmaz | 2 |
| [M402AA](#m402aa) | Rüzgar giriş parçası | |  Pirinç | 6 |
| [H306AA](#h306aa) | Rüzgar giriş kontra somunu | M6 x 3.2mm |  Paslanmaz | 6 |
| [H902AA](#h902aa) | Rüzgar Sensör Hortumu | M6 | Pnomatik Hortumu| 6 |

---
# M201AA Direk &nbsp; &nbsp; 
| Parça Kodu | Parça Açıklaması | Parça Boyutları | Parça Malzemesi | Kullanım Adedi |
|---|---|---|---|---|
| M201AA | Direk |  2 metre? | 50x50x2mm Profil| 1 |

## Açıklama
[Meteoroloji Base Unitesi](../../P101DA-Rain/Readme.md) bu direğin üstüne [Direk Base Bağlantı Parçası](#m102aa-direk-base-bağlantı-parçası) ile bağlanır.</br>
Direğin alt ucu yere saplama şeklinde geçmesi planlanmaktadır.</br>

## Eksikler ve Yapılacaklar
Direğin üst kısmında [Direk Base Bağlantı Parçası](#m102aa-direk-base-bağlantı-parçası)nın bağlanacağı yerdeki deliklerin yeri ve çapı</br>



---

# H302AA Alt Kapak Kalıp İçi Somun &nbsp; &nbsp; 

| Parça Kodu | Parça Açıklaması | Parça Boyutları | Parça Malzemesi | Kullanım Adedi |
|---|---|---|---|---|
| H302AA | Alt Kapak Kalıp İçi Somun | Ø6x14 mm |  Pirinç | 4 |

## Açıklama

[H123AA Saplama](#h302aa-alt-kapak-kalıp-i̇çi-somun)nın bağlandığı somunlardır. </br>


---

# H123AA Base Toplama Saplaması &nbsp; &nbsp; 

| Parça Kodu | Parça Açıklaması | Parça Boyutları | Parça Malzemesi | Kullanım Adedi |
|---|---|---|---|---|
| H123AA | Base Toplama Saplaması | Ø6 - 195 mm |  Paslanmaz | 4 |

## Açıklama
Base ünitesinin [C115AA - Alt Kapak](../C115AA/README.md)'a  bağlanan ve üst kısım hariç diğer parçaları toplayan saplamadır.</br>



---

# H303AA Saplama Sonlandırma Somunu &nbsp; &nbsp; 

| Parça Kodu | Parça Açıklaması | Parça Boyutları | Parça Malzemesi | Kullanım Adedi |
|---|---|---|---|---|
| H303AA | Saplama Sonlandırma Somunu | Ø6 mm Flanşlı |  Paslanmaz | 4 |

## Açıklama
[H123AA Saplaması](../H123AA/Readme.md)nı sonlandıran somunlardır. </br>



---

# M102AA Direk Base Bağlantı Parçası &nbsp; &nbsp; 
| Parça Kodu | Parça Açıklaması | Parça Boyutları | Parça Malzemesi | Kullanım Adedi |
|---|---|---|---|---|
| M102AA | Direk Base Bağlantı Parçası  | |  Paslanmaz | 1 |

## Açıklama
[Direk](#m201aa-direk) ile [P101DA-Base](../../P101DA-Base/Readme.md) üniteyi birleştiren parçadır.</br>
Üzerine 2 adet [Saplama](#h125aa-direk-base-bağlantı-saplaması) kaynatılır.</br>
Bu 2 saplama Direk üzerindeki deliklere geçer ve 2 adet [somun](#h304aa-m6-somun) bağlanır. </br>
Bu parça Ana Üniteye [H124AA Civatası](#h124aa-direk-base-bağlantı-civatası) ve 2 adet [M5 Somun](#h305aa-direk-base-bağlantı-somunu) ile bağlanır. </br>

## Eksikler ve Yapılacaklar
Parçanın çizimi eksik.</br>







---
</br>

# H125AA Direk Base Bağlantı Saplaması  &nbsp; &nbsp; 

| Parça Kodu | Parça Açıklaması | Parça Boyutları | Parça Malzemesi | Kullanım Adedi |
|---|---|---|---|---|
| H125AA | Direk Base Bağlantı Saplaması| Ø6 - 20 mm |  Paslanmaz | 2 |

## Açıklama
Bağlantı parçasının üzerine kaynatılan 2 adet saplamadır.</br>



---

# H304AA M6 Somun   &nbsp; &nbsp; 

| Parça Kodu | Parça Açıklaması | Parça Boyutları | Parça Malzemesi | Kullanım Adedi |
|---|---|---|---|---|
| H304AA | Direk Base Bağlantı Somunu | M6 |  Paslanmaz | 2 |

## Açıklama
Bağlantı parçasının direğe bağlayan somunlardır.</br>



---

# H124AA Direk Base Bağlantı Civatası   &nbsp; &nbsp; 

| Parça Kodu | Parça Açıklaması | Parça Boyutları | Parça Malzemesi | Kullanım Adedi |
|---|---|---|---|---|
| H124AA | Direk Base Bağlantı Civatası | M5x12 mm |  Paslanmaz | 2 |

Bağlantı parçasının Ana üniteye bağlayan civatalardır.</br>


---

# H305AA Direk Base Bağlantı Somunu   &nbsp; &nbsp; 

| Parça Kodu | Parça Açıklaması | Parça Boyutları | Parça Malzemesi | Kullanım Adedi |
|---|---|---|---|---|
| H305AA | Direk Base Bağlantı Somunu | M5 |  Paslanmaz | 2 |

Bağlantı parçasının Ana üniteye bağlayan civataları bağlar.</br>


---
# M402AA Rüzgar Giriş Parçası &nbsp; &nbsp; 
| Parça Kodu | Parça Açıklaması | Parça Boyutları | Parça Malzemesi | Kullanım Adedi |
|---|---|---|---|---|
|  M402AA | Rüzgar giriş parçası | 14x10 mm |  Pirinç | 6 |
## Açıklama
Base ünitesi üzerinde bulunan rüzgar giriş hollerine takılır.</br>
Özel olarak ürettirilmektedir. </br>
m6 x 3.2 mm kontra somun ile bağlanmaktadır. </br>
İç tarafından hortum ile DP sensörlerine bağlanmaktadır. </br>




---

# H306AA Rüzgar giriş kontra somunu &nbsp; &nbsp; 
| Parça Kodu | Parça Açıklaması | Parça Boyutları | Parça Malzemesi | Kullanım Adedi |
|---|---|---|---|---|
|  H306AA | Rüzgar giriş kontra somunu | M6 x 3.2mm |  Paslanmaz | 6 |
## Açıklama
Rüzgar giriş parçasını base üniteye sabitleyen somundur. </br>


---
# H902AA Rüzgar Sensör Hortumu  &nbsp; &nbsp; 
| Parça Kodu | Parça Açıklaması | Parça Boyutları | Parça Malzemesi | Kullanım Adedi |
|---|---|---|---|---|
|  H902AA | Rüzgar Sensör Hortumu | M6 |Pnomatik Hortumu | 6 |
## Açıklama
Rüzgar giriş parçalarından alınan basıncı DP sensörlere ileten hortumdur.</br>


---

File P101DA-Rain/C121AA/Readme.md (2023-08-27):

# C121AA YAĞMUR ÖLÇÜM HUNİ GÖVDE &nbsp; &nbsp; 

| Parça Kodu | Parça Açıklaması | Parça Boyutları | Parça Malzemesi | Kullanım Adedi |
| --- | --- | --- | --- | --- |
| C121AA | Huni gövdesi | Ø218 x 138.4 mm | ABS | 1 |

## Açıklama
Yağmur ölçüm ünitesinin huni gövdesi kısmıdır. Bu ürün 6 xxx vida ile [C122AA](../C122AA/Readme.md) parçasına bağlanır.</br>
Huninin boşaltım deliğinin üst kısmına sert geçme yöntemiyle [C125AA](../C125AA/Readme.md) Orta Kuşkonmaz parçası bağlanır.</br>
Üst kısmında 12 adet 3,2 ?mm kalınlığında [C126AA](../C123AA/Readme.md) Taç kuşkonmaz pimi takılacaktır.</br>

# Maliyet

## __









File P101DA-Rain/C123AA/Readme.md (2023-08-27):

# C123AA YAĞMUR ÖLÇÜM KEPÇE  &nbsp; &nbsp; 
| Parça Kodu | Parça Açıklaması | Parça Boyutları | Parça Malzemesi | Kullanım Adedi |
| --- | --- | --- | --- | --- |
| C123AA | Kepçe | 124x47.5x42 mm  | ABS | 1 |

## Açıklama
Kepçe [Kepçe Bağlantı Pimi H601AA](../H601AA/Readme.md) ile [Alt Gövde](../C122AA/Readme.md)ye bağlanır.</br>
Üzerine 2 adet [Kepçe Mıknatısı H901AA](../H901AA/Readme.md) yapıştırılır.</br>

# Maliyet

# Eksikler ve Yapılacaklar
## __







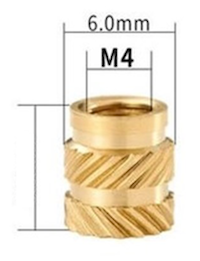
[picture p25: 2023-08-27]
P101DA-Rain/Diğer/2D/insert.png

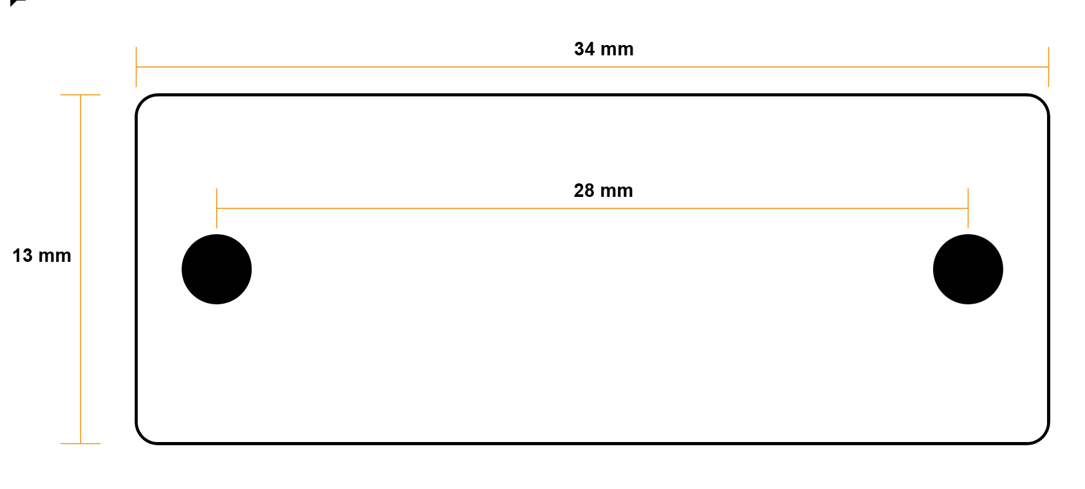
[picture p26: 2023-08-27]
P101DA-Base/C111DA/Documents/UV_PCB_Dimension.png

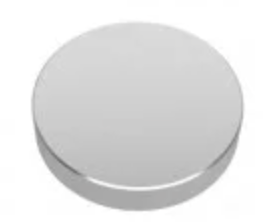
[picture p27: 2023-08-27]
P101DA-Rain/Diğer/2D/mıknatıs.png

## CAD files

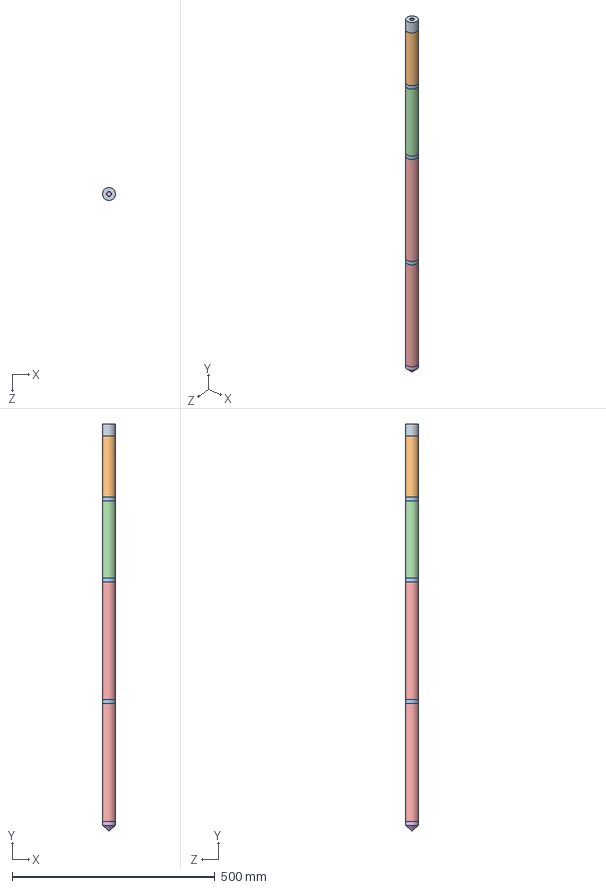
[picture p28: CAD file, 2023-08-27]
P101DA-Soil/Solidworks/Soil_Montaj.SLDASM
32.0 x 1004.0 x 32.0 mm
yivli son
15 cm
yivli ara x 3
19 cm
29 cm x 2
yivli baş

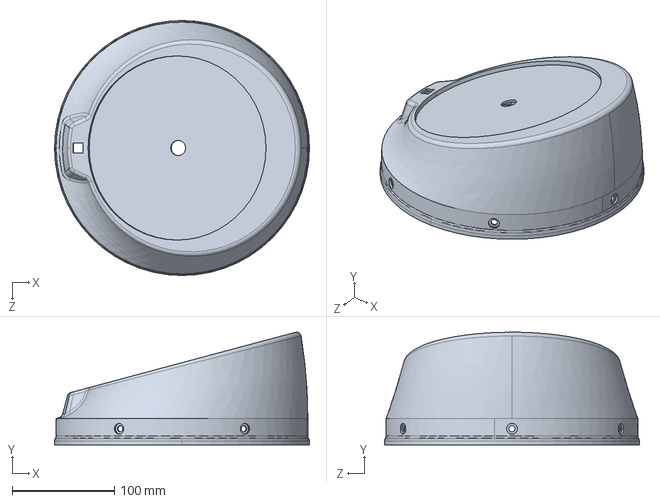
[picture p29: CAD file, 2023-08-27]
P101DA-Base/C111DA/3D/C111DA_R2.STEP
249.3 x 110.2 x 249.3 mm

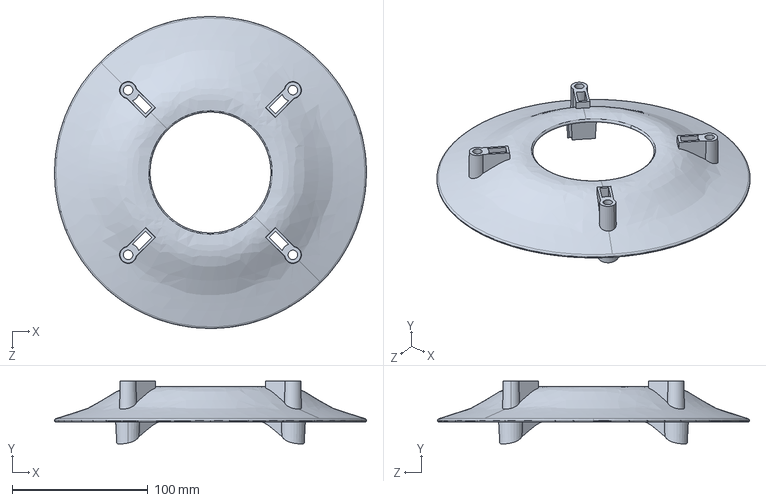
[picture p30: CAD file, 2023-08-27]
P101DA-Base/C112BA/3D/C112BA.STEP
230.0 x 46.4 x 230.0 mm

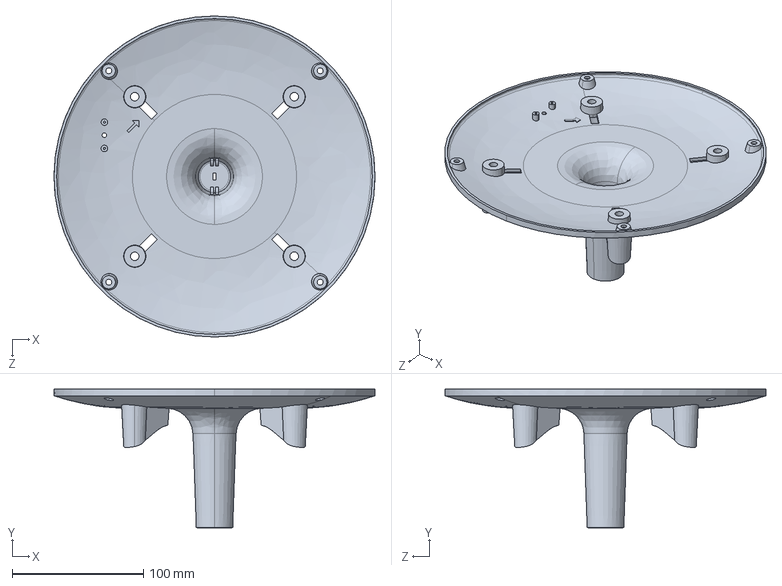
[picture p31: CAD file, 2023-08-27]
P101DA-Base/C113CA/3D/C113CA_R2.STEP
244.4 x 105.5 x 244.4 mm

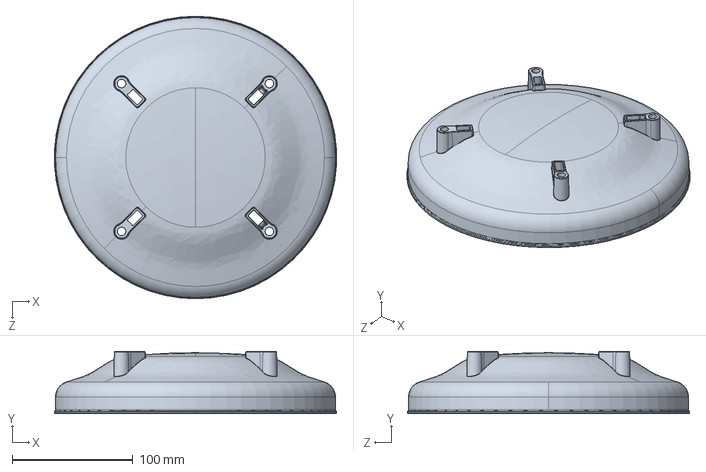
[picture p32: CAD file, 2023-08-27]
P101DA-Base/C114CA/3D/C114CA.STEP
233.5 x 51.6 x 233.9 mm

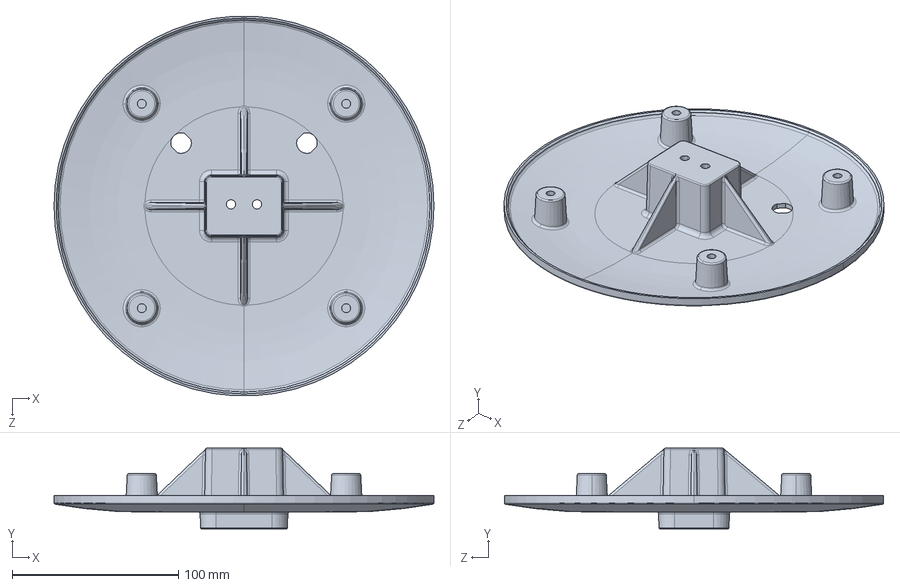
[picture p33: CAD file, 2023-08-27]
P101DA-Base/C115BA/3D/C115AA.STEP
228.5 x 48.5 x 228.2 mm

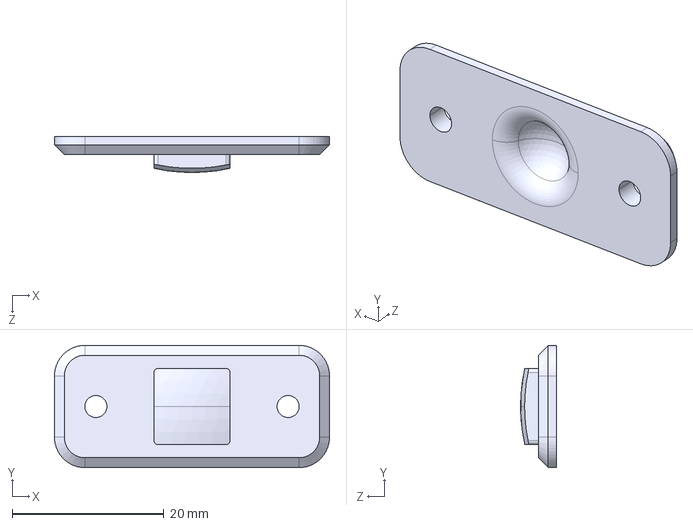
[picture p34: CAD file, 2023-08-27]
P101DA-Base/C116AA/3D/C116AA.STEP
36.2 x 16.1 x 4.75 mm

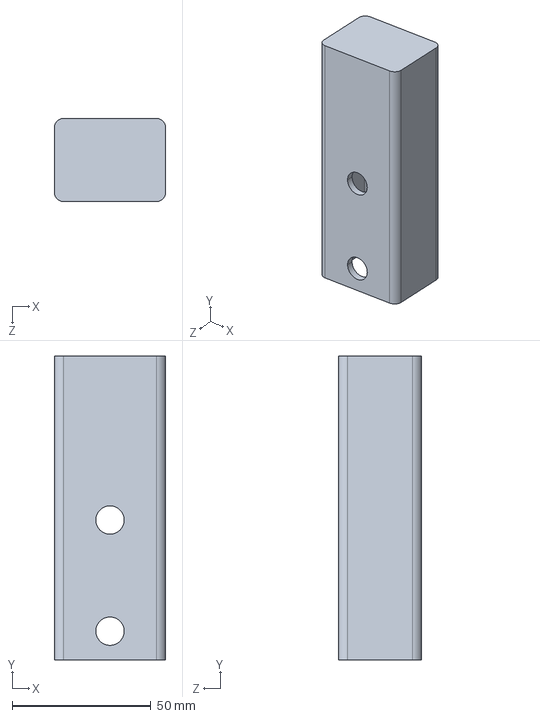
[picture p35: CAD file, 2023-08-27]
P101DA-Base/Diğer/3D/M102AA.STEP
40.0 x 109.4 x 29.9 mm

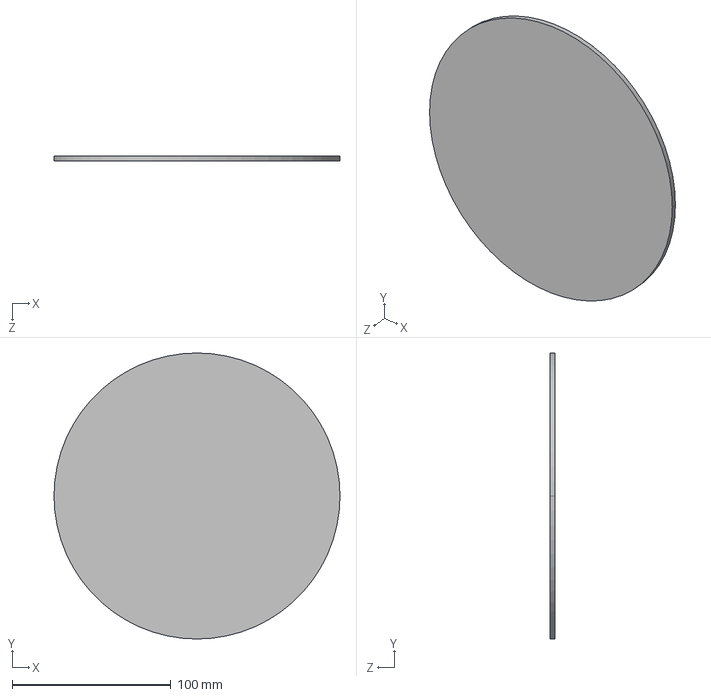
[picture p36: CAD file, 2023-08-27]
P101DA-Base/PV Cell/3D/PV Cell.STEP
180.0 x 180.0 x 3.00 mm

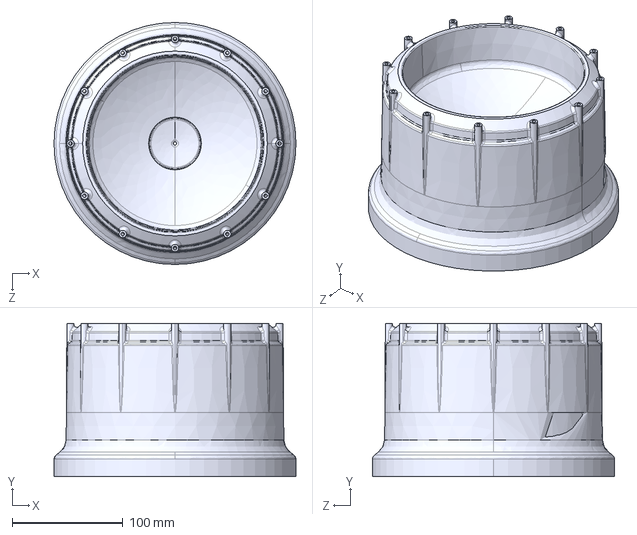
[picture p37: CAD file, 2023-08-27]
P101DA-Rain/C121AA/3D/C121AA Huni Govdesi-1.STEP
218.3 x 138.4 x 218.3 mm

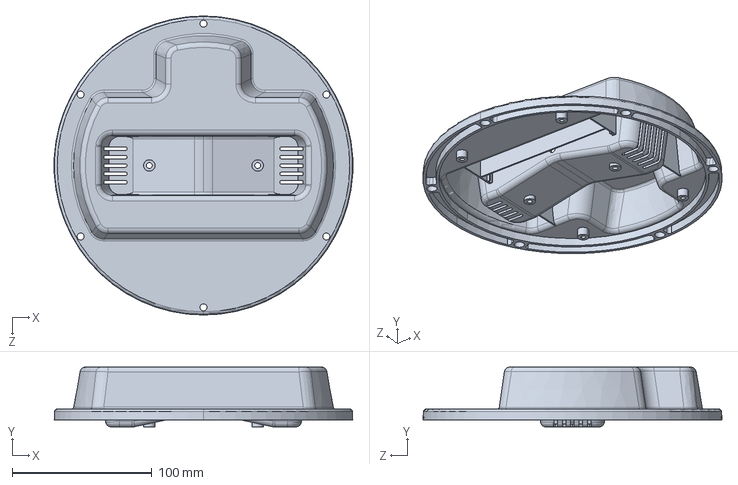
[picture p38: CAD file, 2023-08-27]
P101DA-Rain/C122AA/3D/C122AA.STEP
213.4 x 42.8 x 213.7 mm

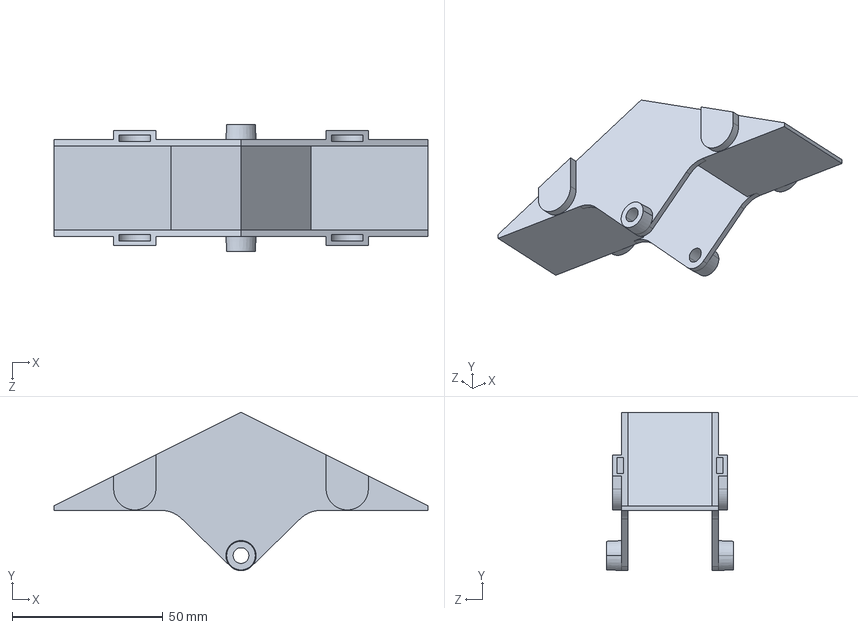
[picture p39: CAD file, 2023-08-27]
P101DA-Rain/C123AA/3D/C123AA Kepce.STEP
124.0 x 52.5 x 42.0 mm

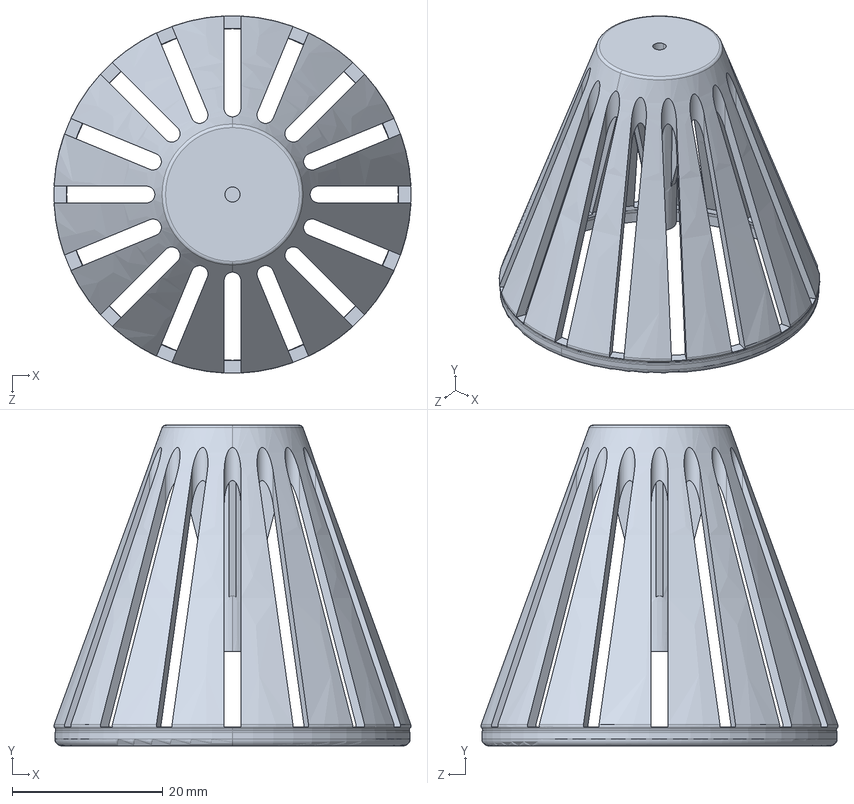
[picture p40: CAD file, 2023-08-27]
P101DA-Rain/C125AA/3D/C125AA.STEP
47.3 x 42.5 x 47.3 mm

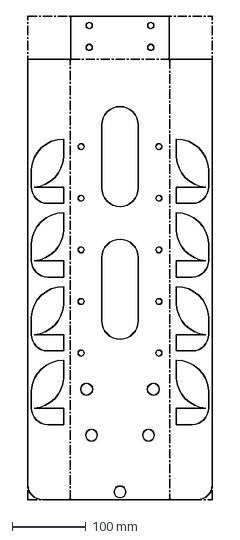
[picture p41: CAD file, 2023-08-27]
P101DA-Rain/M101AA/DXF/M101AA_kesim_bukum.DXF
250.1 x 655.4 mm

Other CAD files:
P101DA-Base/C111DA/SolidWorks/kart vida deliği kısaltıldı./C111DA_R2.STEP
P101DA-Base/C115BA/SolidWorks/C115AA1.SLDPRT
P101DA-Rain/C121AA/SolidWorks/kepçeye çarpıyor.SLDPRT
P101DA-Rain/M301AA/DXF/3mm plastik altı dış 1 adet.DXF
P101DA-Base/C111DA/3D/C111DA_R2.x_t
P101DA-Base/C111DA/Old/C111DA.SLDPRT
P101DA-Base/C111DA/Old/C111DA.STEP
P101DA-Base/C111DA/Old/C111DA.x_t
P101DA-Base/C111DA/Old/C111DA_R1.SLDPRT
P101DA-Base/C111DA/Old/C111DA_R1.STEP
P101DA-Base/C111DA/SolidWorks/C111DA_R2.SLDPRT
P101DA-Base/C111DA/SolidWorks/kart vida deliği kısaltıldı./C111DA_R2.SLDPRT
P101DA-Base/C111DA/SolidWorks/kart vida deliği kısaltıldı./C111DA_R2.STL
P101DA-Base/C112BA/2D/C112BA.SLDDRW
P101DA-Base/C112BA/SolidWorks/C112BA.SLDPRT
P101DA-Base/C113CA/SolidWorks/C113CA_R2.SLDPRT
P101DA-Base/C113CA/old/C113BA.SLDDRW
P101DA-Base/C113CA/old/C113BA.STEP
P101DA-Base/C113CA/old/C113CA_R1.SLDPRT
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

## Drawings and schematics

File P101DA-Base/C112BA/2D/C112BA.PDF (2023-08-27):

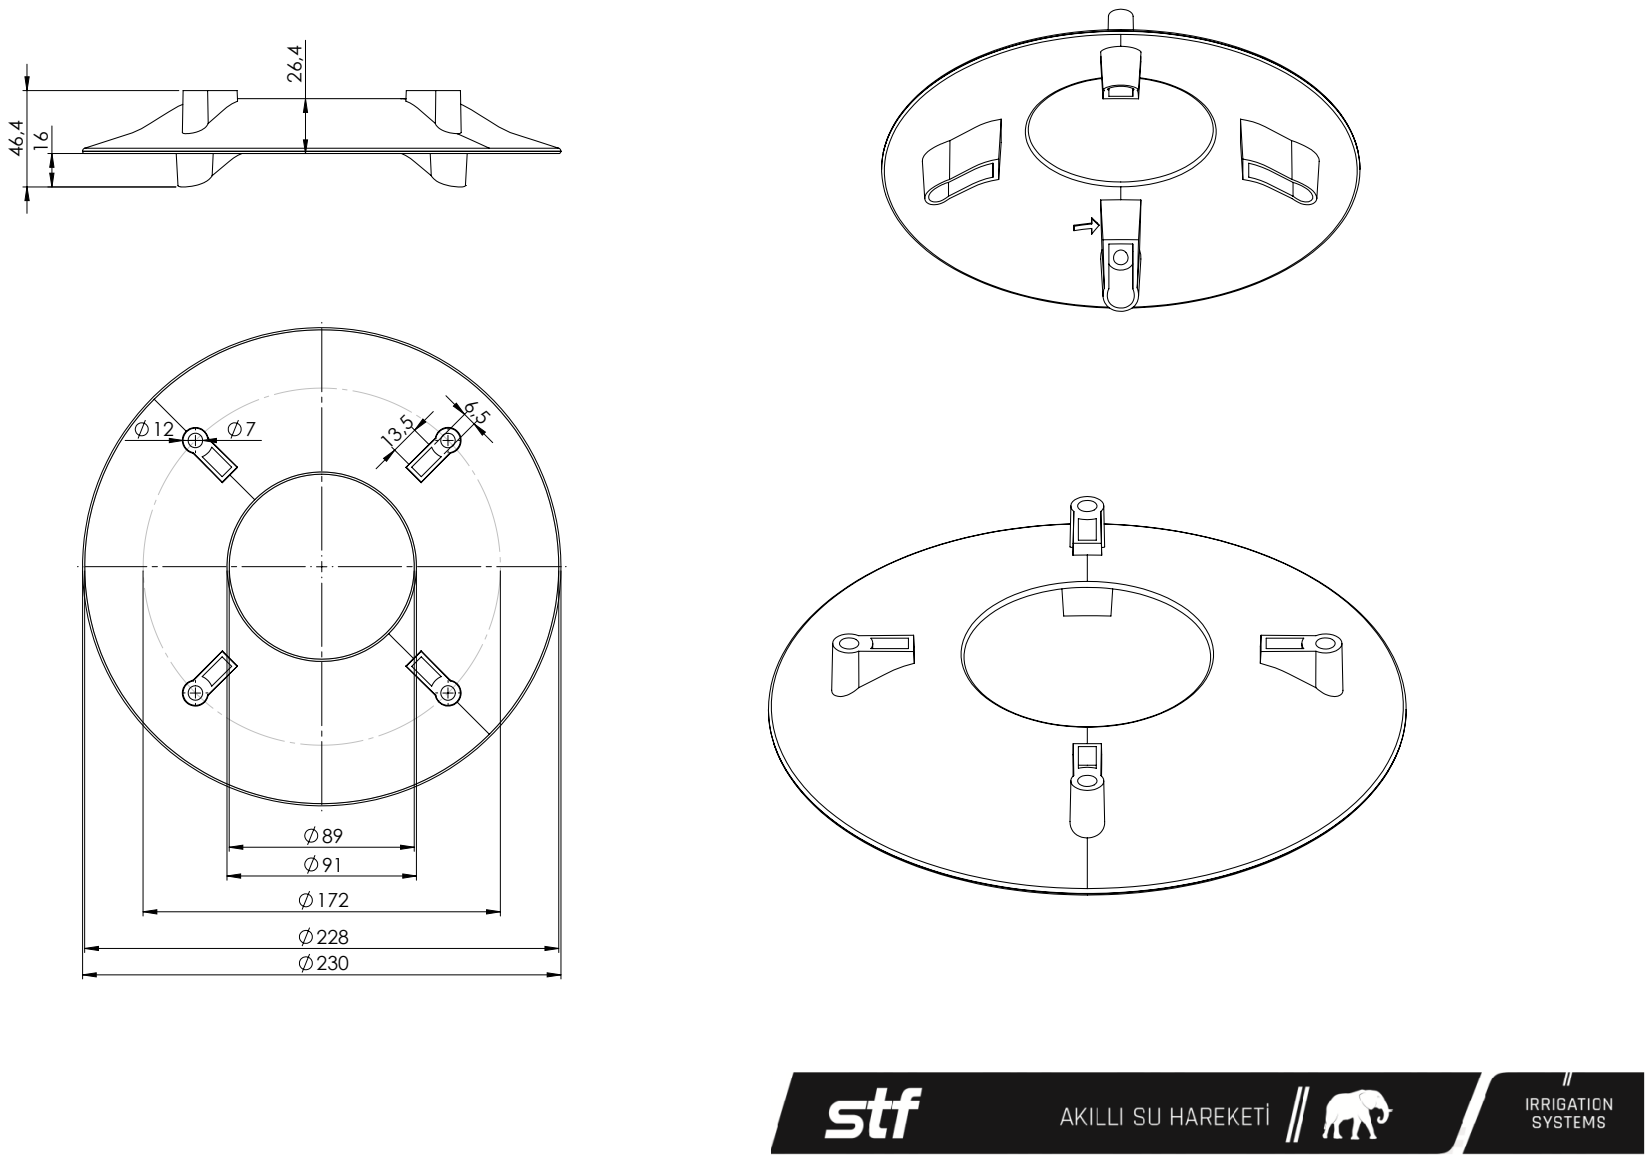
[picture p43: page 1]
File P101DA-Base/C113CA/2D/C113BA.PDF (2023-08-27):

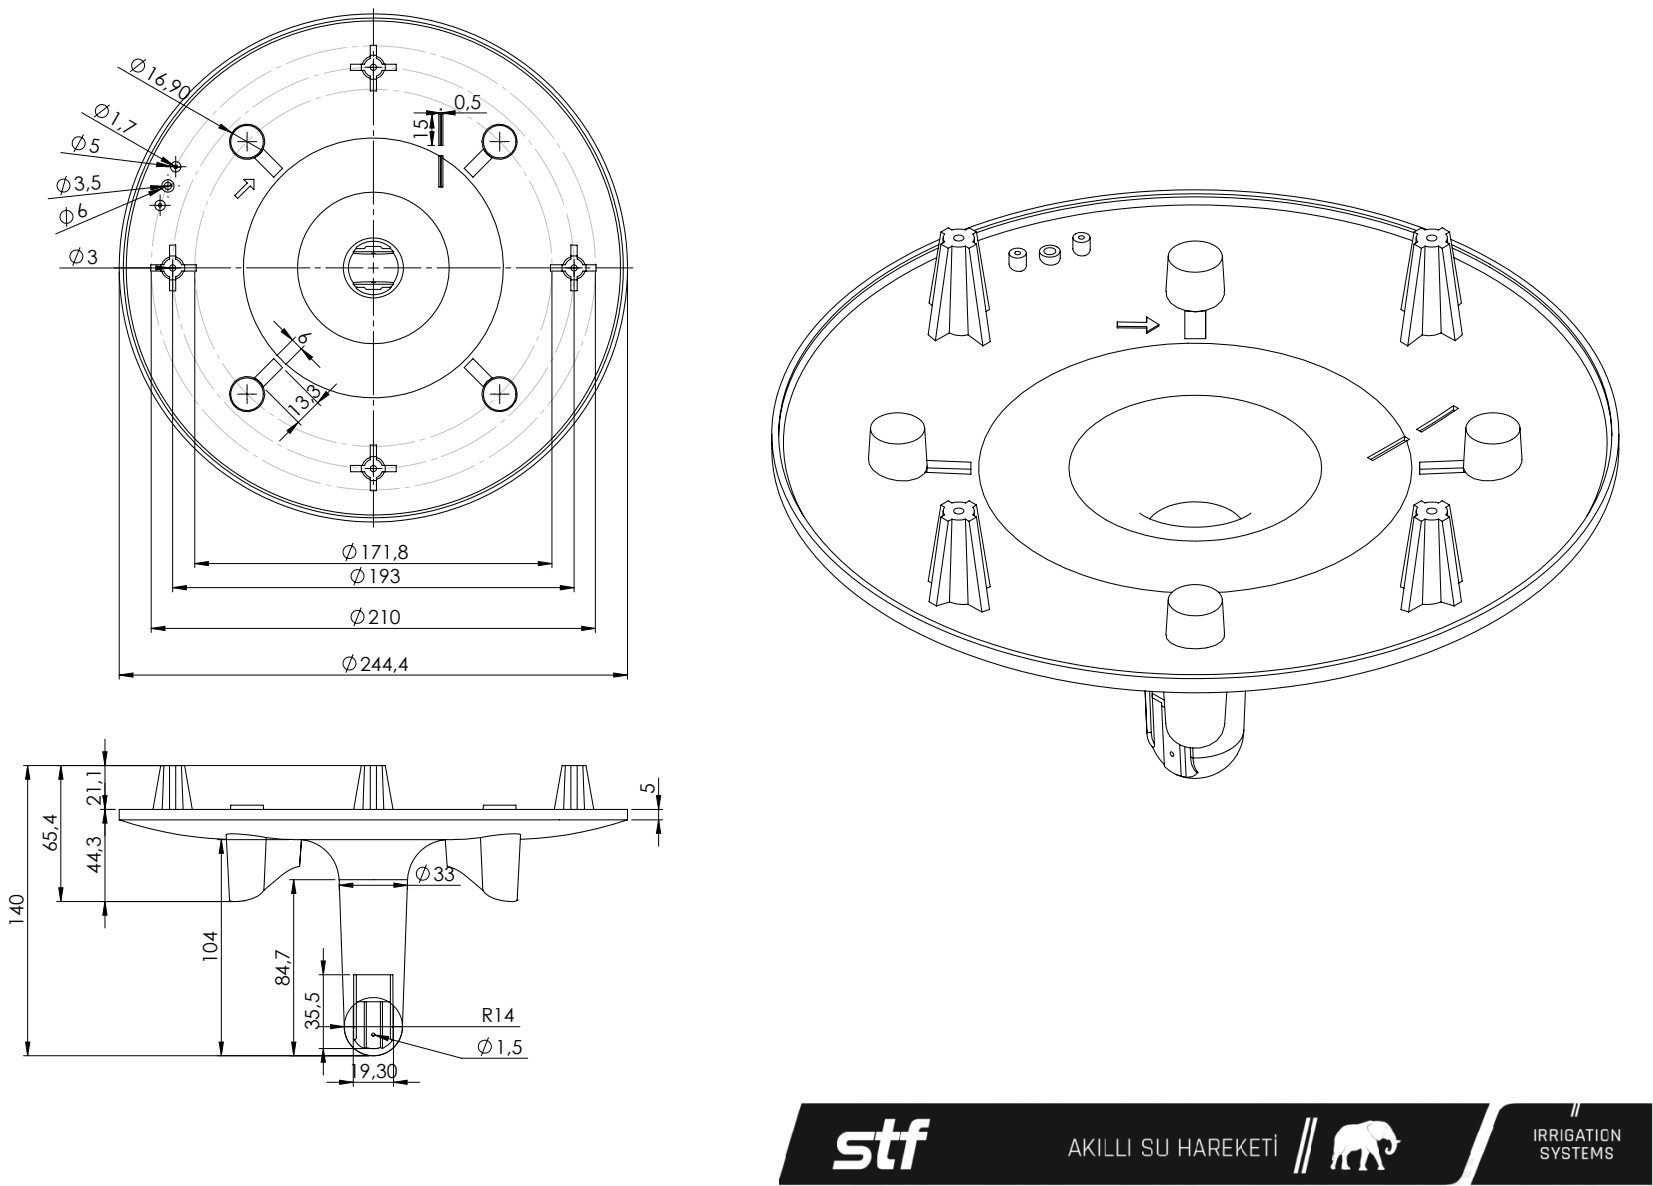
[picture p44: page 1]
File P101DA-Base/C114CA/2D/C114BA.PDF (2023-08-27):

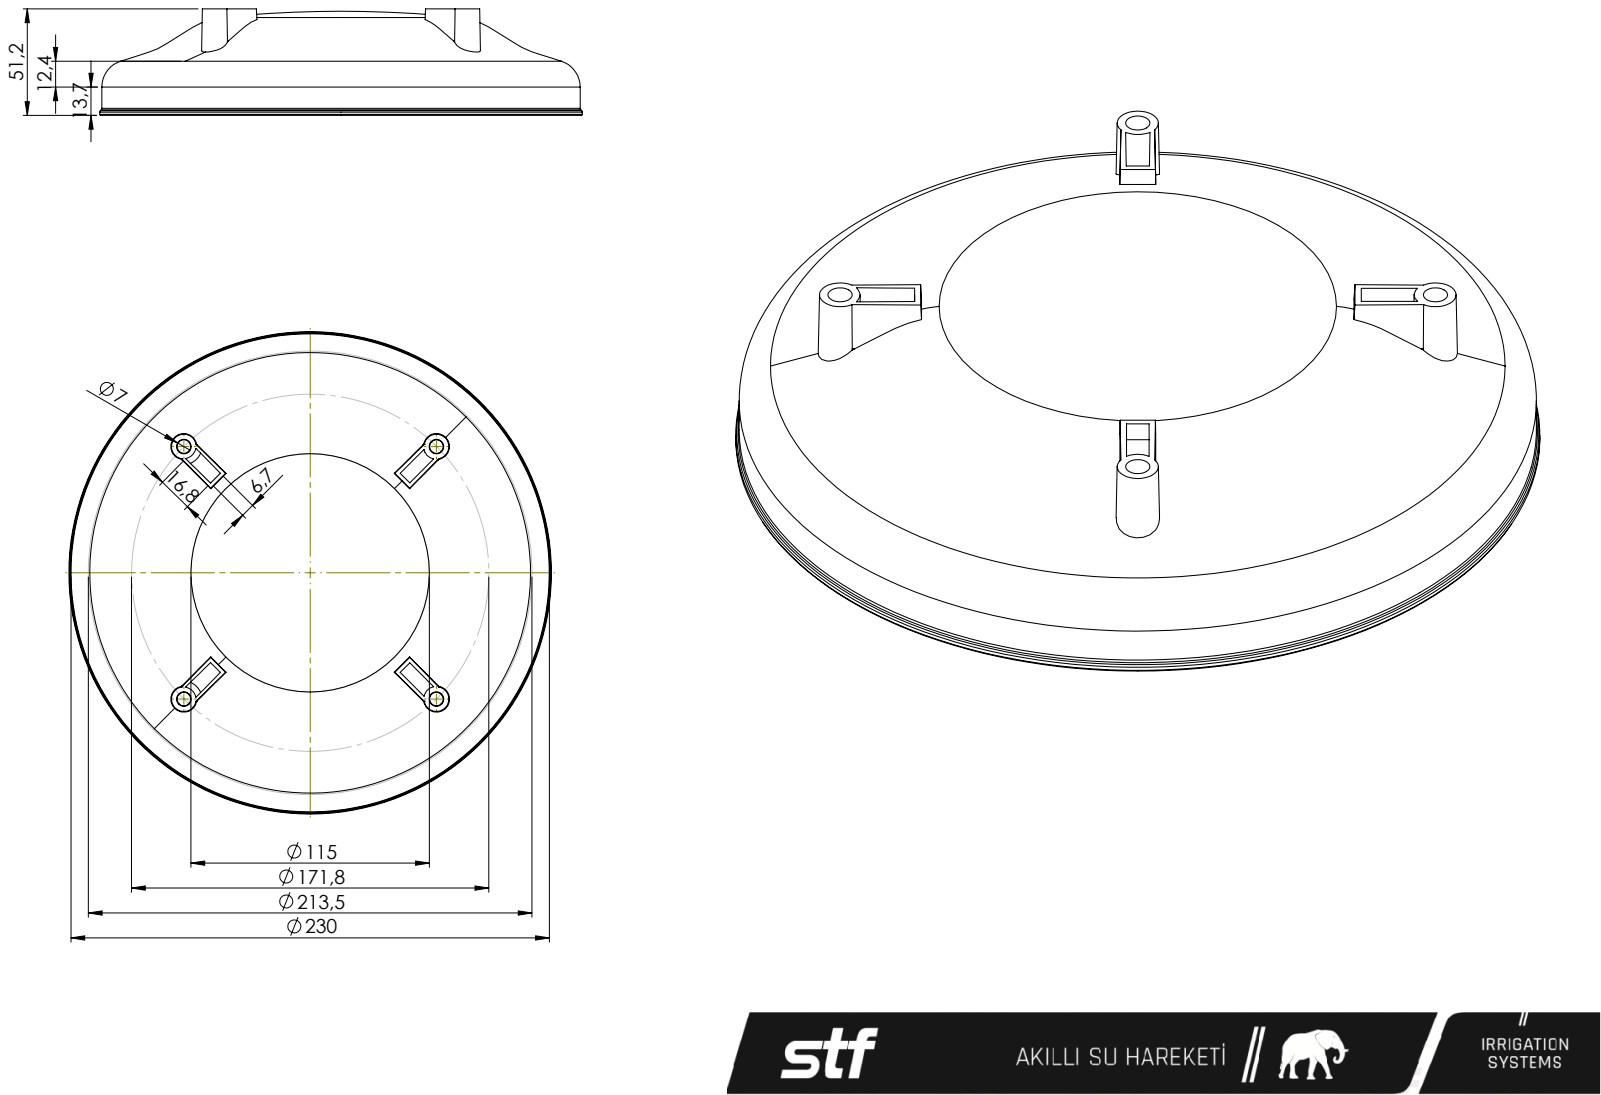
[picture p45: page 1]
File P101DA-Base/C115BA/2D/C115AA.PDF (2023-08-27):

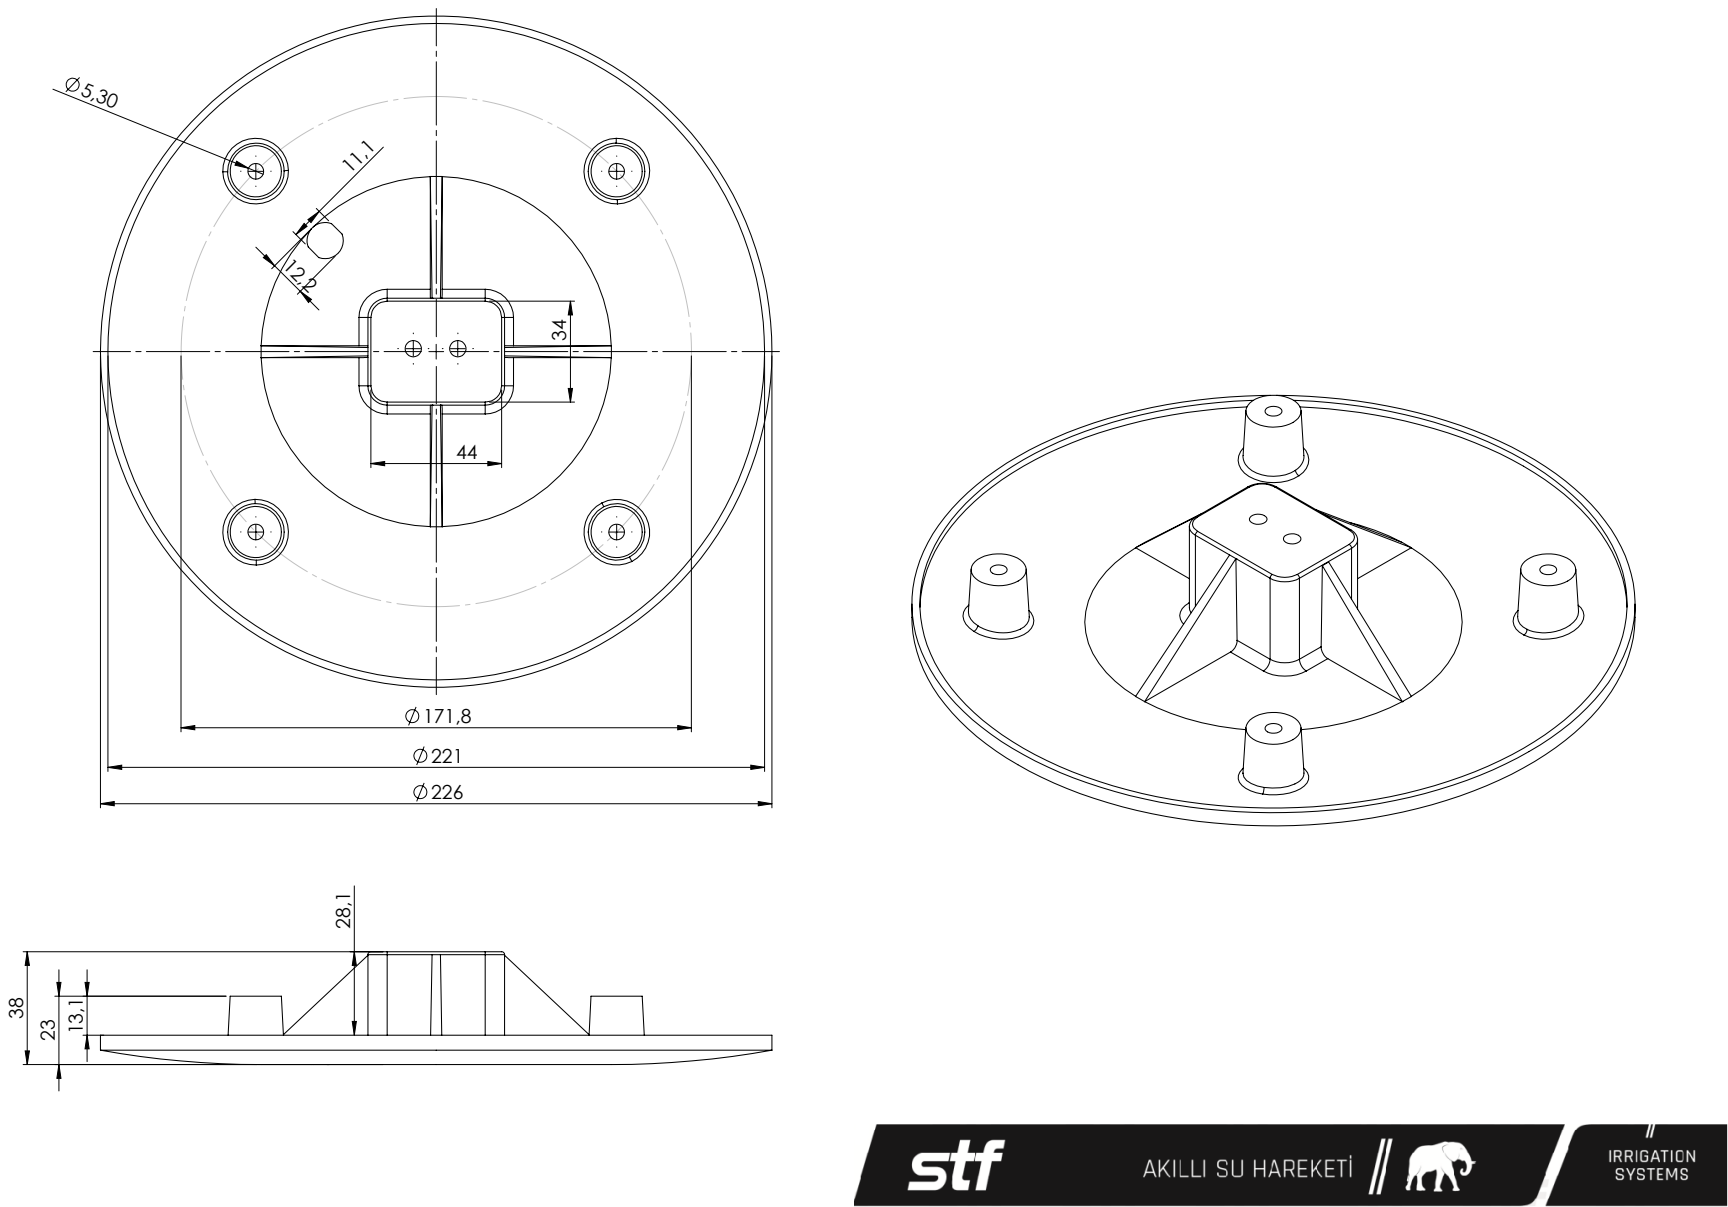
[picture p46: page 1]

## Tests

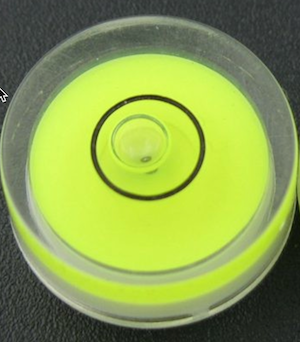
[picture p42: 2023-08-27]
P101DA-Rain/Diğer/2D/bubble_measurement.png
